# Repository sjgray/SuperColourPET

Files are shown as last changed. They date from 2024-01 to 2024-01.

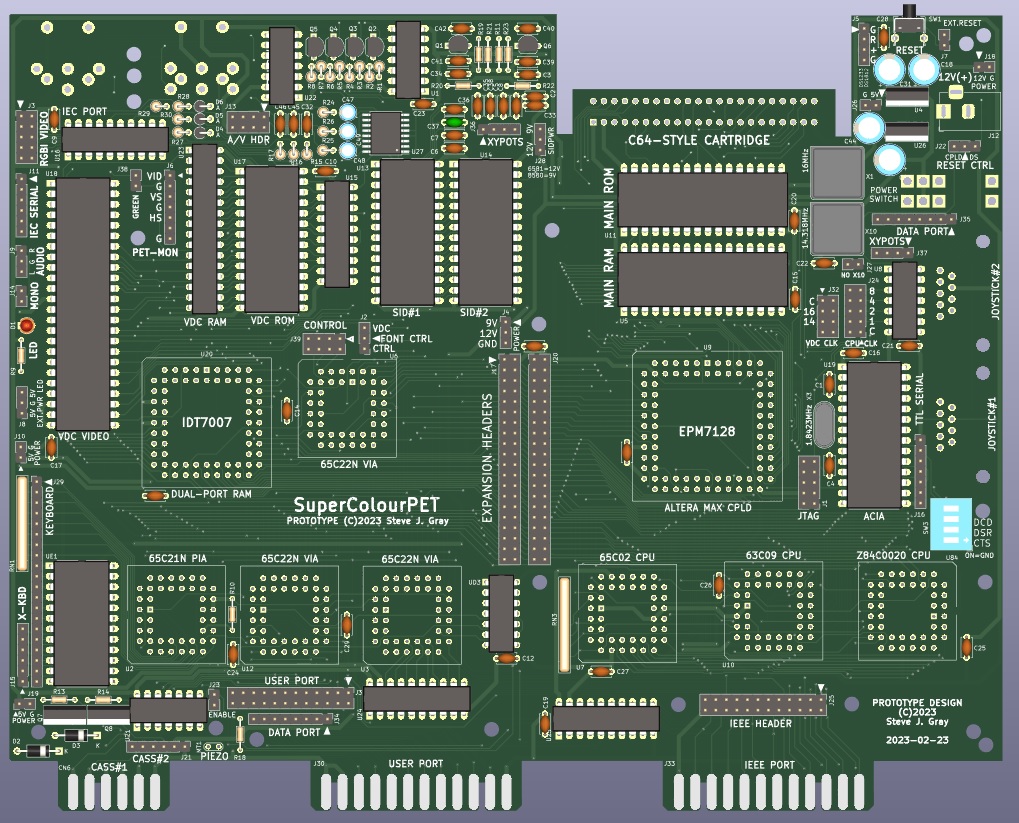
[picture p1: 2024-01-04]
PCB/Proto/_Pics/SuperColourPET-Render-2023-02-23.jpg

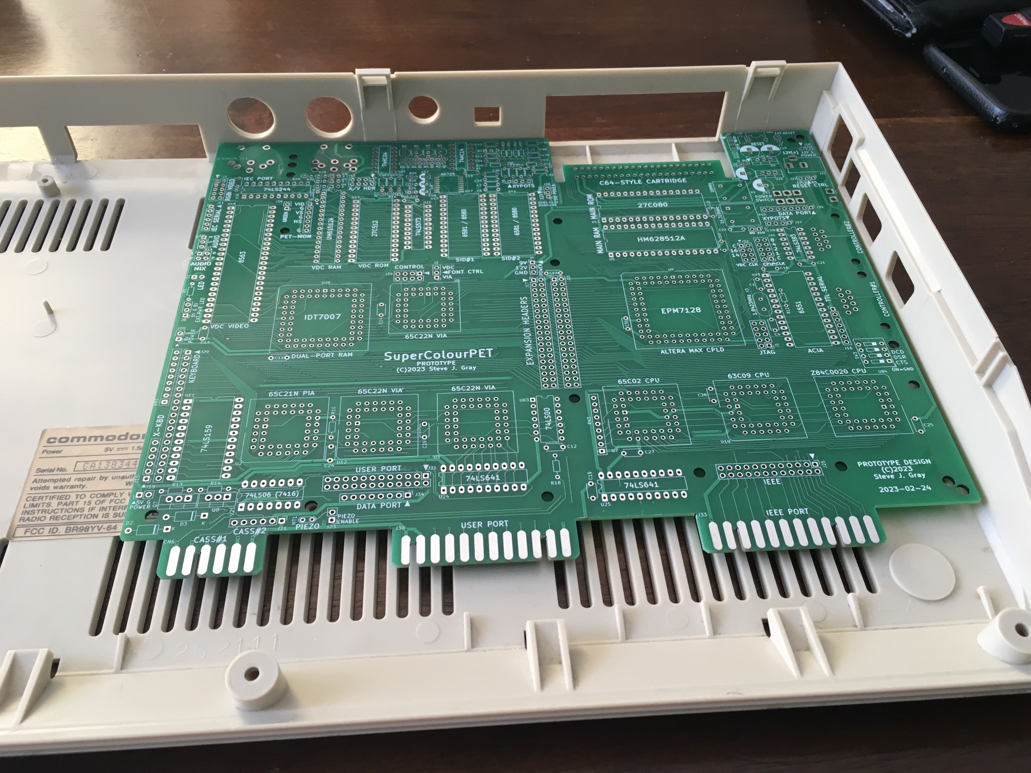
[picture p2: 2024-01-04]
PCB/Proto/_Pics/PCBs-Arrived-2023-03-02.jpg

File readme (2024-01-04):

SuperColourPET
==============

Introduction
------------

This is a project to create a Commodore SuperPET compatible computer with Colour. My ColourPET project aimed to add colour to a standard PET computer. While successful, ultimately I determined that adding all the features I wanted, like 80 column mode and graphics, would require too much hacking of a PET motherboard to be practical. So, I moved on to other projects. Recently I worked on the CLCD recreation project which provided the foundation for a nice 80 column 16-colour RGBI video using a 8563 VDC chip. This chip also supports graphics and software-defined fonts. I've also been interested in the dual-CPU SuperPET, with a 6809 CPU. So naturally I thought why not combine these things together? The result is the SuperColourPET (SCP). On top of that I wanted to go one more step to add a Z80 CPU for CP/M capabilities.

Recently there has been interest in PET replacement boards fitting in standard PET cases and talk of also putting them in C64 cases. Why not both? So I've come up with a single board design that will fit in PET, C64 (breadbin), and 64C cases. When installed in a PET case all three ports on the back will be the same as a regular PET board. The 2nd cassette port will be available on a header. When installed in a C64-type case it provides access to a C64 compatible audio/video port, semi-compatible C64 cartridge port, IEC port, power, and two configurable joystick ports. The board only takes up 2/3 of the C64 case and the C64 cassette and user-port cutouts will be free. I will be designing different boards that can be mounted here for access to PET cassette and USER port, or to IEEE and RGBI port etc. All the ports on the board have headers so you can select which ports you want to extend out those two openings.

Status
------

2023-02-24 - Prototype design complete. PCB's have been made. Project is on hold.
2024-01-04 - Github created. Posted Kicad design files.

*** The PROTO board has not been populated nor verified as working!!!!!
*** No CPLD code is written. Firmware is in planning stage.
*** This project should be considered as PRE-ALPHA! Use at own risk. Design subject to change!!!!!!!!!!!!!!!

That being said, much of the design is derived from my Commodore CLCD design, which is at the stage of basic
operation. The PET circuitry is based on the standard PET design. I am planning to build this bit-by-bit
starting with PET functionality and slowly adding the other CPU's over time. This is a long-term project!

Steve

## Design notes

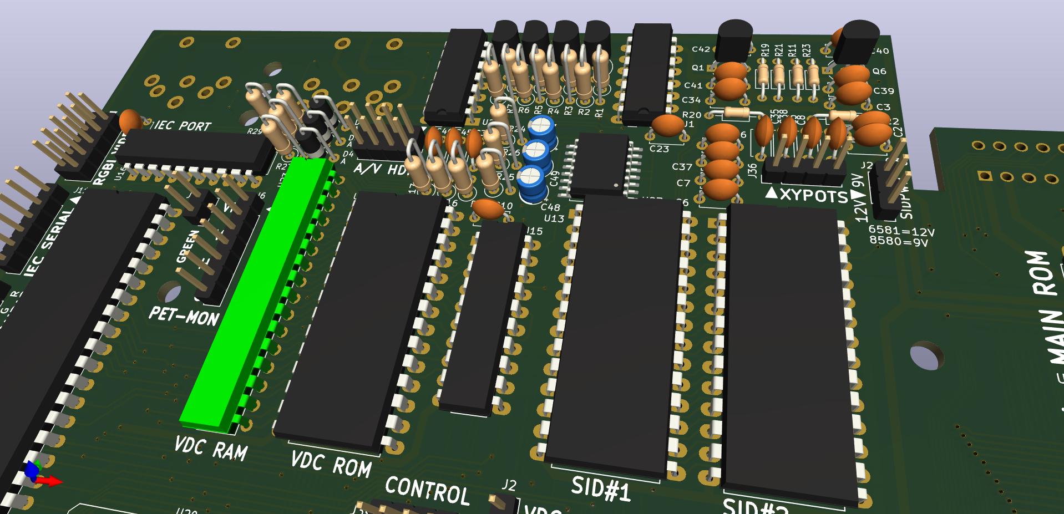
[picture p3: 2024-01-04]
PCB/Proto/_Pics/SuperColourPET-Render-2023-02-23b.jpg

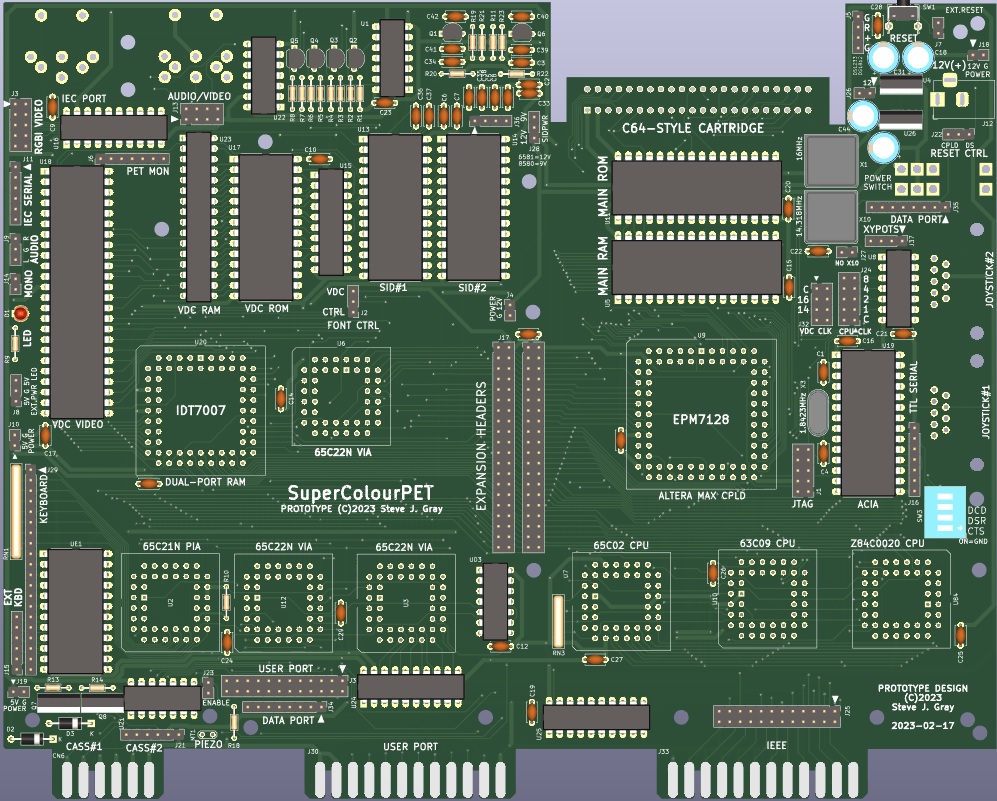
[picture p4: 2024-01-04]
PCB/Proto/_Pics/SuperColourPET.jpg

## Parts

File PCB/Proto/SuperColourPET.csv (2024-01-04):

Source: | C:\Users\sjgra\Desktop\Projects\KiCadProjects\SuperColourPET\SuperColourPET.kicad_sch
Date: | 2023-02-24 9:52:36 PM
Tool: | Eeschema (6.0.5)
Generator: | C:\Program Files\KiCad\6.0\bin\scripting\plugins/bom_csv_grouped_by_value.py
Component Count: | 178
Individual Components:
Item | Qty | Reference(s) | Value | LibPart | Footprint | Datasheet | Manufacturer_Name | Manufacturer_Part_Number
 |  | C1 | 10K | Super8296-rescue:C-superpet-rescue | Capacitor_THT:C_Disc_D4.7mm_W2.5mm_P5.00mm
 |  | C2 | .1 | Device:C_Small | Capacitor_THT:C_Disc_D4.7mm_W2.5mm_P5.00mm | ~
 |  | C3 | .1 | Device:C_Small | Capacitor_THT:C_Disc_D4.7mm_W2.5mm_P5.00mm | ~
 |  | C4 | 22pF | Super8296-rescue:C-superpet-rescue | Capacitor_THT:C_Disc_D4.7mm_W2.5mm_P5.00mm
 |  | C5 | 1800pF | Device:C_Small | Capacitor_THT:C_Disc_D4.7mm_W2.5mm_P5.00mm | ~
 |  | C6 | 470pF | Device:C_Small | Capacitor_THT:C_Disc_D4.7mm_W2.5mm_P5.00mm | ~
 |  | C7 | 470pF | Device:C_Small | Capacitor_THT:C_Disc_D4.7mm_W2.5mm_P5.00mm | ~
 |  | C8 | 1800pF | Device:C_Small | Capacitor_THT:C_Disc_D4.7mm_W2.5mm_P5.00mm | ~
 |  | C9 | 0.1 | device1:C_Small | Capacitor_THT:C_Disc_D4.7mm_W2.5mm_P5.00mm | ~
 |  | C10 | 0.1 | device1:C_Small | Capacitor_THT:C_Disc_D4.7mm_W2.5mm_P5.00mm | ~
 |  | C11 | 0.1 | device1:C_Small | Capacitor_THT:C_Disc_D4.7mm_W2.5mm_P5.00mm | ~
 |  | C12 | 0.1 | device1:C_Small | Capacitor_THT:C_Disc_D4.7mm_W2.5mm_P5.00mm | ~
 |  | C13 | 0.1 | device1:C_Small | Capacitor_THT:C_Disc_D4.7mm_W2.5mm_P5.00mm | ~
 |  | C14 | 0.1 | device1:C_Small | Capacitor_THT:C_Disc_D4.7mm_W2.5mm_P5.00mm | ~
 |  | C15 | 0.1 | device1:C_Small | Capacitor_THT:C_Disc_D4.7mm_W2.5mm_P5.00mm | ~
 |  | C16 | 0.1 | device1:C_Small | Capacitor_THT:C_Disc_D4.7mm_W2.5mm_P5.00mm | ~
 |  | C17 | 0.1 | device1:C_Small | Capacitor_THT:C_Disc_D4.7mm_W2.5mm_P5.00mm | ~
 |  | C18 | 10uF | Device:C_Polarized | Capacitor_THT:CP_Radial_D7.5mm_P2.50mm | ~
 |  | C19 | 0.1 | device1:C_Small | Capacitor_THT:C_Disc_D4.7mm_W2.5mm_P5.00mm | ~
 |  | C20 | 0.1 | device1:C_Small | Capacitor_THT:C_Disc_D4.7mm_W2.5mm_P5.00mm | ~
 |  | C21 | 0.1 | device1:C_Small | Capacitor_THT:C_Disc_D4.7mm_W2.5mm_P5.00mm | ~
 |  | C22 | 0.1 | device1:C_Small | Capacitor_THT:C_Disc_D4.7mm_W2.5mm_P5.00mm | ~
 |  | C23 | 0.1 | device1:C_Small | Capacitor_THT:C_Disc_D4.7mm_W2.5mm_P5.00mm | ~
 |  | C24 | 0.1 | device1:C_Small | Capacitor_THT:C_Disc_D4.7mm_W2.5mm_P5.00mm | ~
 |  | C25 | 0.1 | device1:C_Small | Capacitor_THT:C_Disc_D4.7mm_W2.5mm_P5.00mm | ~
 |  | C26 | 0.1 | device1:C_Small | Capacitor_THT:C_Disc_D4.7mm_W2.5mm_P5.00mm | ~
 |  | C27 | 0.1 | device1:C_Small | Capacitor_THT:C_Disc_D4.7mm_W2.5mm_P5.00mm | ~
 |  | C28 | 0.01uf * | device1:C_Small | Capacitor_THT:C_Disc_D4.7mm_W2.5mm_P5.00mm | ~
 |  | C29 | 0.1 | device1:C_Small | Capacitor_THT:C_Disc_D4.7mm_W2.5mm_P5.00mm | ~
 |  | C30 | 0.1 | device1:C_Small | Capacitor_THT:C_Disc_D4.7mm_W2.5mm_P5.00mm | ~
 |  | C31 | 10uF | Device:C_Polarized | Capacitor_THT:CP_Radial_D7.5mm_P2.50mm | ~
 |  | C32 | 0.1 | device1:C_Small | Capacitor_THT:C_Disc_D4.7mm_W2.5mm_P5.00mm | ~
 |  | C33 | .1 | Device:C_Small | Capacitor_THT:C_Disc_D4.7mm_W2.5mm_P5.00mm | ~
 |  | C34 | .1 | Device:C_Small | Capacitor_THT:C_Disc_D4.7mm_W2.5mm_P5.00mm | ~
 |  | C35 | 1800pF | Device:C_Small | Capacitor_THT:C_Disc_D4.7mm_W2.5mm_P5.00mm | ~
 |  | C36 | 470pF | Device:C_Small | Capacitor_THT:C_Disc_D4.7mm_W2.5mm_P5.00mm | ~
 |  | C37 | 470pF | Device:C_Small | Capacitor_THT:C_Disc_D4.7mm_W2.5mm_P5.00mm | ~
 |  | C38 | 1800pF | Device:C_Small | Capacitor_THT:C_Disc_D4.7mm_W2.5mm_P5.00mm | ~
 |  | C39 | NC | Device:C_Small | Capacitor_THT:C_Disc_D4.7mm_W2.5mm_P5.00mm | ~
 |  | C40 | .1 | Device:C_Small | Capacitor_THT:C_Disc_D4.7mm_W2.5mm_P5.00mm | ~
 |  | C41 | NC | Device:C_Small | Capacitor_THT:C_Disc_D4.7mm_W2.5mm_P5.00mm | ~
 |  | C42 | .1 | Device:C_Small | Capacitor_THT:C_Disc_D4.7mm_W2.5mm_P5.00mm | ~
 |  | C43 | 10uF | Device:C_Polarized | Capacitor_THT:CP_Radial_D7.5mm_P2.50mm | ~
 |  | C44 | 10uF | Device:C_Polarized | Capacitor_THT:CP_Radial_D7.5mm_P2.50mm | ~
 |  | C45 | 0.1 | device1:C_Small | Capacitor_THT:C_Disc_D4.7mm_W2.5mm_P5.00mm | ~
 |  | C46 | 0.1 | device1:C_Small | Capacitor_THT:C_Disc_D4.7mm_W2.5mm_P5.00mm | ~
 |  | C47 | 220uF | Device:C_Polarized | Capacitor_THT:CP_Radial_D4.0mm_P1.50mm | ~
 |  | C48 | 220uF | Device:C_Polarized | Capacitor_THT:CP_Radial_D4.0mm_P1.50mm | ~
 |  | C49 | 220uF | Device:C_Polarized | Capacitor_THT:CP_Radial_D4.0mm_P1.50mm | ~
 |  | C50 | 0.1 | device1:C_Small | Capacitor_THT:C_Disc_D4.7mm_W2.5mm_P5.00mm | ~
 |  | CN1 | SERIAL_BUS_CON | KU-schematics-library:SERIAL_BUS_CON | KU-14194HB-RevB-KiCad:SERIAL_CON_DIN6
 |  | CN2 | EXPANSION_PORT | KU-schematics-library:EXPANSION_PORT | KU-14194HB-RevB-KiCad:EXPANSION_PORT
 |  | CN6 | CASS1 | KU-schematics-library:CASSETTE_PORT_CON | KU-14194HB-RevB-KiCad:EDGE_CON_12P_TAPE
 |  | CN8 | CONTROL_PORT | KU-schematics-library:CONTROL_PORT | KU-14194HB-RevB-KiCad:JOYPORT_DB9
 |  | CN9 | CONTROL_PORT | KU-schematics-library:CONTROL_PORT | KU-14194HB-RevB-KiCad:JOYPORT_DB9
 |  | CN10 | AV_CONN | KU-schematics-library:AV_CONN | KU-14194HB-RevB-KiCad:AV_CON_DIN8
 |  | D1 | LED | Device:LED | LED_THT:LED_D3.0mm | ~
 |  | D2 | 7V5 | Device:D_Zener | Diode_THT:D_A-405_P10.16mm_Horizontal | ~
 |  | D3 | 7V5 | Device:D_Zener | Diode_THT:D_A-405_P10.16mm_Horizontal | ~
 |  | D4 | D | Device:D | Diode_THT:D_A-405_P2.54mm_Vertical_AnodeUp | ~
 |  | D5 | D | Device:D | Diode_THT:D_A-405_P2.54mm_Vertical_AnodeUp | ~
 |  | D6 | D | Device:D | Diode_THT:D_A-405_P2.54mm_Vertical_AnodeUp | ~
 |  | J1 | JTAG | Super8296-rescue:Conn_02x05_Odd_Even-superpet-rescue | Connector_PinHeader_2.54mm:PinHeader_2x05_P2.54mm_Vertical
 |  | J2 | GRAPHSEL | Connector_Generic:Conn_01x03 | Connector_PinHeader_2.54mm:PinHeader_1x03_P2.54mm_Vertical | ~
 |  | J3 | RGBI Header | Connector_Generic:Conn_02x05_Odd_Even | Connector_PinHeader_2.54mm:PinHeader_2x05_P2.54mm_Vertical | ~
 |  | J4 | POWER TAP | Connector_Generic:Conn_01x03 | Connector_PinHeader_2.54mm:PinHeader_1x03_P2.54mm_Vertical | ~
 |  | J5 | DS OPT | Connector_Generic:Conn_01x04 | Connector_PinHeader_2.54mm:PinHeader_1x04_P2.54mm_Vertical | ~
 |  | J6 | INTERNAL MONITOR | Connector_Generic:Conn_01x07 | Connector_PinHeader_2.54mm:PinHeader_1x07_P2.54mm_Vertical | ~
 |  | J7 | RESET | Connector_Generic:Conn_01x02 | Connector_PinHeader_2.54mm:PinHeader_1x02_P2.54mm_Vertical | ~
 |  | J8 | POWER LED | Connector_Generic:Conn_01x03 | Connector_PinHeader_2.54mm:PinHeader_1x03_P2.54mm_Vertical | ~
 |  | J9 | AUDIO | Connector_Generic:Conn_01x03 | Connector_PinHeader_2.54mm:PinHeader_1x03_P2.54mm_Vertical | ~
 |  | J10 | POWER5V | Connector_Generic:Conn_01x02 | Connector_PinHeader_2.54mm:PinHeader_1x02_P2.54mm_Vertical | ~
 |  | J11 | IEC Header | Connector_Generic:Conn_01x06 | Connector_PinHeader_2.54mm:PinHeader_1x06_P2.54mm_Vertical | ~
 |  | J12 | POWER_IN | Connector:Barrel_Jack_Switch | Connector_BarrelJack:BarrelJack_Horizontal | ~
 |  | J13 | AV HEADER | Connector_Generic:Conn_02x04_Odd_Even | Connector_PinHeader_2.54mm:PinHeader_2x04_P2.54mm_Vertical | ~
 |  | J14 | AUDIOMIX | Connector_Generic:Conn_02x02_Counter_Clockwise | Connector_PinHeader_2.54mm:PinHeader_2x02_P2.54mm_Vertical | ~
 |  | J15 | Extended Kbd | Connector_Generic:Conn_01x06 | Connector_PinHeader_2.54mm:PinHeader_1x06_P2.54mm_Vertical | ~
 |  | J16 | TTL Header | Connector_Generic:Conn_01x07 | Connector_PinHeader_2.54mm:PinHeader_1x07_P2.54mm_Vertical | ~
 |  | J17 | Expansion | Connector_Generic:Conn_02x20_Odd_Even | Connector_PinHeader_2.54mm:PinHeader_2x20_P2.54mm_Vertical | ~
 |  | J18 | POWER12V | Connector_Generic:Conn_01x02 | Connector_PinHeader_2.54mm:PinHeader_1x02_P2.54mm_Vertical | ~
 |  | J19 | POWER5V | Connector_Generic:Conn_01x02 | Connector_PinHeader_2.54mm:PinHeader_1x02_P2.54mm_Vertical | ~
 |  | J20 | Expansion | Connector_Generic:Conn_02x20_Odd_Even | Connector_PinHeader_2.54mm:PinHeader_2x20_P2.54mm_Vertical | ~
 |  | J21 | CASS2 | Connector_Generic:Conn_01x06 | Connector_PinHeader_2.54mm:PinHeader_1x06_P2.54mm_Vertical | ~
 |  | J22 | RESET | Connector_Generic:Conn_01x03 | Connector_PinHeader_2.54mm:PinHeader_1x03_P2.54mm_Vertical | ~
 |  | J23 | PIEZO ENABLE | Connector_Generic:Conn_01x02 | Connector_PinHeader_2.54mm:PinHeader_1x02_P2.54mm_Vertical | ~
 |  | J24 | CPU Clock | Connector_Generic:Conn_02x05_Odd_Even | Connector_PinHeader_2.54mm:PinHeader_2x05_P2.54mm_Vertical | ~
 |  | J25 | IEEE | Connector_Generic:Conn_02x12_Odd_Even | Connector_PinHeader_2.54mm:PinHeader_2x12_P2.54mm_Vertical | ~
 |  | J26 | POWER5V | Connector_Generic:Conn_01x02 | Connector_PinHeader_2.54mm:PinHeader_1x02_P2.54mm_Vertical | ~
 |  | J27 | NO-X10 | Connector_Generic:Conn_01x02 | Connector_PinHeader_2.54mm:PinHeader_1x02_P2.54mm_Vertical | ~
 |  | J28 | SIDPWR | Connector_Generic:Conn_01x03 | Connector_PinHeader_2.54mm:PinHeader_1x03_P2.54mm_Vertical | ~
 |  | J29 | PET KEYBOARD | Connector_Generic:Conn_01x20 | Connector_PinHeader_2.54mm:PinHeader_1x20_P2.54mm_Vertical | ~
 |  | J30 | USERPORT | Super8296-rescue:EDGE_CON_02x12-cbm | KU-14194HB-RevB-KiCad:EDGE_CON_24P
 |  | J31 | USERPORT | Connector_Generic:Conn_02x12_Odd_Even | Connector_PinHeader_2.54mm:PinHeader_2x12_P2.54mm_Vertical | ~
 |  | J32 | VDC Clock | Connector_Generic:Conn_02x04_Odd_Even | Connector_PinHeader_2.54mm:PinHeader_2x04_P2.54mm_Vertical | ~
 |  | J33 | IEEE | Super8296-rescue:EDGE_CON_02x12-cbm | KU-14194HB-RevB-KiCad:EDGE_CON_24P
 |  | J34 | USERDATA | Connector_Generic:Conn_01x08 | Connector_PinHeader_2.54mm:PinHeader_1x08_P2.54mm_Vertical | ~
 |  | J35 | USERJOY | Connector_Generic:Conn_01x08 | Connector_PinHeader_2.54mm:PinHeader_1x08_P2.54mm_Vertical | ~
 |  | J36 | POTS | Connector_Generic:Conn_01x04 | Connector_PinHeader_2.54mm:PinHeader_1x04_P2.54mm_Vertical | ~
 |  | J37 | POTS | Connector_Generic:Conn_01x04 | Connector_PinHeader_2.54mm:PinHeader_1x04_P2.54mm_Vertical | ~
 |  | J38 | VID-GRN | Connector_Generic:Conn_01x02 | Connector_PinHeader_2.54mm:PinHeader_1x02_P2.54mm_Vertical | ~
 |  | J39 | Control | Connector_Generic:Conn_02x04_Odd_Even | Connector_PinHeader_2.54mm:PinHeader_2x04_P2.54mm_Vertical | ~
 |  | MT1 | Piezo | Device:Speaker | TestPoint:TestPoint_2Pads_Pitch2.54mm_Drill0.8mm | ~
 |  | Q1 | 2SC1815 | Transistor_BJT:2SC1815 | Package_TO_SOT_THT:TO-92_Inline_Wide | https://media.digikey.com/pdf/Data%20Sheets/Toshiba%20PDFs/2SC1815.pdf
 |  | Q2 | 2N3904 | Transistor_BJT:2N3904 | Package_TO_SOT_THT:TO-92_Inline_Wide | https://www.onsemi.com/pub/Collateral/2N3903-D.PDF
 |  | Q3 | 2N3904 | Transistor_BJT:2N3904 | Package_TO_SOT_THT:TO-92_Inline_Wide | https://www.onsemi.com/pub/Collateral/2N3903-D.PDF
 |  | Q4 | 2N3904 | Transistor_BJT:2N3904 | Package_TO_SOT_THT:TO-92_Inline_Wide | https://www.onsemi.com/pub/Collateral/2N3903-D.PDF
 |  | Q5 | 2N3904 | Transistor_BJT:2N3904 | Package_TO_SOT_THT:TO-92_Inline_Wide | https://www.onsemi.com/pub/Collateral/2N3903-D.PDF
 |  | Q6 | 2SC1815 | Transistor_BJT:2SC1815 | Package_TO_SOT_THT:TO-92_Inline_Wide | https://media.digikey.com/pdf/Data%20Sheets/Toshiba%20PDFs/2SC1815.pdf
 |  | Q7 | TIP110 | Device:Q_NPN_Darlington_BCE | Package_TO_SOT_THT:TO-220-3_Vertical | ~
 |  | Q8 | TIP110 | Device:Q_NPN_Darlington_BCE | Package_TO_SOT_THT:TO-220-3_Vertical | ~
 |  | R1 | 1K | Device:R | Resistor_THT:R_Axial_DIN0207_L6.3mm_D2.5mm_P2.54mm_Vertical | ~
 |  | R2 | 4K7 | Device:R | Resistor_THT:R_Axial_DIN0207_L6.3mm_D2.5mm_P2.54mm_Vertical | ~
 |  | R3 | 4K7 | Device:R | Resistor_THT:R_Axial_DIN0207_L6.3mm_D2.5mm_P2.54mm_Vertical | ~
 |  | R4 | 4K7 | Device:R | Resistor_THT:R_Axial_DIN0207_L6.3mm_D2.5mm_P2.54mm_Vertical | ~
 |  | R5 | 1K | Device:R | Resistor_THT:R_Axial_DIN0207_L6.3mm_D2.5mm_P2.54mm_Vertical | ~
 |  | R6 | 4K7 | Device:R | Resistor_THT:R_Axial_DIN0207_L6.3mm_D2.5mm_P2.54mm_Vertical | ~
 |  | R7 | 1K | Device:R | Resistor_THT:R_Axial_DIN0207_L6.3mm_D2.5mm_P2.54mm_Vertical | ~
 |  | R8 | 4K7 | Device:R | Resistor_THT:R_Axial_DIN0207_L6.3mm_D2.5mm_P2.54mm_Vertical | ~
 |  | R9 | 10K | KU-schematics-library:R_US_CUSTOM | Resistor_THT:R_Axial_DIN0204_L3.6mm_D1.6mm_P7.62mm_Horizontal
 |  | R10 | 1K | Device:R | Resistor_THT:R_Axial_DIN0204_L3.6mm_D1.6mm_P7.62mm_Horizontal | ~
 |  | R11 | 1K | KU-schematics-library:R_US_CUSTOM | Resistor_THT:R_Axial_DIN0204_L3.6mm_D1.6mm_P7.62mm_Horizontal
 |  | R12 | 1M | Device:R | Resistor_THT:R_Axial_DIN0204_L3.6mm_D1.6mm_P7.62mm_Horizontal | ~
 |  | R13 | R | Device:R | Resistor_THT:R_Axial_DIN0204_L3.6mm_D1.6mm_P7.62mm_Horizontal | ~
 |  | R14 | R | Device:R | Resistor_THT:R_Axial_DIN0204_L3.6mm_D1.6mm_P7.62mm_Horizontal | ~
 |  | R15 | 75R | Device:R | Resistor_THT:R_Axial_DIN0207_L6.3mm_D2.5mm_P2.54mm_Vertical | ~
 |  | R16 | 75R | Device:R | Resistor_THT:R_Axial_DIN0207_L6.3mm_D2.5mm_P2.54mm_Vertical | ~
 |  | R17 | 75R | Device:R | Resistor_THT:R_Axial_DIN0207_L6.3mm_D2.5mm_P2.54mm_Vertical | ~
 |  | R18 | 10 ohm | device1:R | Resistor_THT:R_Axial_DIN0204_L3.6mm_D1.6mm_P7.62mm_Horizontal | ~
 |  | R19 | 1K | KU-schematics-library:R_US_CUSTOM | Resistor_THT:R_Axial_DIN0204_L3.6mm_D1.6mm_P7.62mm_Horizontal
 |  | R20 | 10K | KU-schematics-library:R_US_CUSTOM | Resistor_THT:R_Axial_DIN0204_L3.6mm_D1.6mm_P7.62mm_Horizontal
 |  | R21 | 1K | KU-schematics-library:R_US_CUSTOM | Resistor_THT:R_Axial_DIN0204_L3.6mm_D1.6mm_P7.62mm_Horizontal
 |  | R22 | 10K | KU-schematics-library:R_US_CUSTOM | Resistor_THT:R_Axial_DIN0204_L3.6mm_D1.6mm_P7.62mm_Horizontal
 |  | R23 | 1K | KU-schematics-library:R_US_CUSTOM | Resistor_THT:R_Axial_DIN0204_L3.6mm_D1.6mm_P7.62mm_Horizontal
 |  | R24 | 75R | Device:R | Resistor_THT:R_Axial_DIN0207_L6.3mm_D2.5mm_P2.54mm_Vertical | ~
 |  | R25 | 75R | Device:R | Resistor_THT:R_Axial_DIN0207_L6.3mm_D2.5mm_P2.54mm_Vertical | ~
 |  | R26 | 75R | Device:R | Resistor_THT:R_Axial_DIN0207_L6.3mm_D2.5mm_P2.54mm_Vertical | ~
 |  | R27 | 75R | Device:R | Resistor_THT:R_Axial_DIN0207_L6.3mm_D2.5mm_P2.54mm_Vertical | ~
 |  | R28 | 75R | Device:R | Resistor_THT:R_Axial_DIN0207_L6.3mm_D2.5mm_P2.54mm_Vertical | ~
 |  | R29 | 75R | Device:R | Resistor_THT:R_Axial_DIN0207_L6.3mm_D2.5mm_P2.54mm_Vertical | ~
 |  | R30 | 75R | Device:R | Resistor_THT:R_Axial_DIN0207_L6.3mm_D2.5mm_P2.54mm_Vertical | ~
 |  | RN1 | 10K | Device:R_Network08_US | Resistor_THT:R_Array_SIP9 | http://www.vishay.com/docs/31509/csc.pdf
 |  | RN3 | CPU pullups | Device:R_Network08 | Resistor_THT:R_Array_SIP9 | http://www.vishay.com/docs/31509/csc.pdf
 |  | SW1 | RESET | Switch:SW_Push | Button_Switch_THT:SW_Tactile_SPST_Angled_PTS645Vx58-2LFS | ~
 |  | SW3 | COM Lines | Switch:SW_DIP_x04 | Button_Switch_THT:SW_DIP_SPSTx04_Slide_9.78x12.34mm_W7.62mm_P2.54mm | ~
 |  | SW4 | POWER_SWITCH | KU-schematics-library:POWER_SWITCH | KU-14194HB-RevB-KiCad:POWER_SWITCH
 |  | U1 | 74HC14 | 74xx:74HC14 | Package_DIP:DIP-14_W7.62mm_LongPads | http://www.ti.com/lit/gpn/sn74HC14
 |  | U2 | W65C21NxPL | 65xx:W65C21NxPL | Package_LCC:PLCC-44_THT-Socket | http://www.westerndesigncenter.com/wdc/documentation/w65c21.pdf
 |  | U3 | W65C21NxPL | 65xx:W65C21NxPL | Package_LCC:PLCC-44_THT-Socket | http://www.westerndesigncenter.com/wdc/documentation/w65c21.pdf
 |  | U4 | LM7805_TO220 | Regulator_Linear:LM7805_TO220 | Package_TO_SOT_THT:TO-220-3_Vertical | https://www.onsemi.cn/PowerSolutions/document/MC7800-D.PDF
 |  | U5 | HM628512A | Super8296-rescue:HM628512A-superpet-rescue | Package_DIP:DIP-32_W15.24mm_LongPads
 |  | U6 | W65C22NxPL | 65xx:W65C22NxPL | Package_LCC:PLCC-44_THT-Socket | http://www.westerndesigncenter.com/wdc/documentation/w65c22.pdf
 |  | U7 | W65C02SxPL | 65xx:W65C02SxPL | Package_LCC:PLCC-44_THT-Socket | http://www.westerndesigncenter.com/wdc/documentation/w65c02s.pdf
 |  | U8 | 74LS393 | 74xx:74LS393 | Package_DIP:DIP-14_W7.62mm_LongPads | 74xx\74LS393.pdf
 |  | U9 | EPM7128S | Super8296-rescue:EPM7128S-superpet-rescue | Package_LCC:PLCC-84_THT-Socket
 |  | U10 | MC6809E-PLCC | cbm-steve:MC6809E-PLCC | Package_LCC:PLCC-44_THT-Socket
 |  | U11 | 27C080 | Memory_EPROM:27C080 | Package_DIP:DIP-32_W15.24mm_LongPads | http://ww1.microchip.com/downloads/en/devicedoc/doc0360.pdf
 |  | U12 | W65C22NxPL | 65xx:W65C22NxPL | Package_LCC:PLCC-44_THT-Socket | http://www.westerndesigncenter.com/wdc/documentation/w65c22.pdf
 |  | U13 | 6581 | KU-schematics-library:SID | Package_DIP:DIP-28_W15.24mm_LongPads
 |  | U14 | 6581 | KU-schematics-library:SID | Package_DIP:DIP-28_W15.24mm_LongPads
 |  | U15 | 74LS573 | 74xx:74LS573 | Package_DIP:DIP-20_W7.62mm_LongPads | 74xx/74hc573.pdf
 |  | U16 | 74LS244 | 74xx:74LS244 | Package_DIP:DIP-20_W7.62mm_LongPads | http://www.ti.com/lit/ds/symlink/sn74ls244.pdf
 |  | U17 | 27C512 | cbm:27C512 | Package_DIP:DIP-28_W15.24mm_LongPads
 |  | U18 | 8563 | cbm:8563 | Package_DIP:DIP-48_W15.24mm_LongPads
 |  | U19 | 6551 | Super8296-rescue:6551-superpet-rescue | Package_DIP:DIP-28_W15.24mm_LongPads
 |  | U20 | IDT7007PLCC | cbm:IDT7007PLCC | Package_LCC:PLCC-68_THT-Socket
 |  | U21 | 7416 | 74xx_IEEE:7416 | Package_DIP:DIP-14_W7.62mm_LongPads
 |  | U22 | 74LS04 | 74xx:74LS04 | Package_DIP:DIP-14_W7.62mm_LongPads | http://www.ti.com/lit/gpn/sn74LS04
 |  | U23 | UM61512A | cbm-steve:UM61512A | Package_DIP:DIP-32_W7.62mm
 |  | U24 | 74LS641 | 74xx_IEEE:74LS641 | Package_DIP:DIP-20_W7.62mm_LongPads
 |  | U25 | 74LS641 | 74xx_IEEE:74LS641 | Package_DIP:DIP-20_W7.62mm_LongPads
 |  | U26 | LM7809_TO220 | Regulator_Linear:LM7809_TO220 | Package_TO_SOT_THT:TO-220-3_Vertical | https://www.onsemi.cn/PowerSolutions/document/MC7800-D.PDF
 |  | U27 | AD725 | Video:AD725 | Package_SO:SOIC-16W_7.5x10.3mm_P1.27mm | https://www.analog.com/media/en/technical-documentation/data-sheets/AD725.pdf
 |  | U84 | Z80CPU-LCC | Zilog_z80:Z80CPU-LCC | Package_LCC:PLCC-44_THT-Socket | https://www.mouser.co.uk/datasheet/2/450/ps0178-19386.pdf | Zilog | Z84C00
 |  | UD3 | 74LS00 | 74xx:74LS00 | Package_DIP:DIP-14_W7.62mm | http://www.ti.com/lit/gpn/sn74ls00
 |  | UE1 | 74159 | 74xx_IEEE:74159 | Package_DIP:DIP-24_W15.24mm_LongPads
 |  | X1 | CXO_DIP8 | Oscillator:CXO_DIP8 | Oscillator:Oscillator_DIP-8 | http://cdn-reichelt.de/documents/datenblatt/B400/OSZI.pdf
 |  | X3 | 1.8432 MHz, HC49U | Super8296-rescue:Crystal-superpet-rescue | Crystal:Crystal_HC49-U_Vertical
 |  | X10 | CXO_DIP8 | Oscillator:CXO_DIP8 | Oscillator:Oscillator_DIP-8 | http://cdn-reichelt.de/documents/datenblatt/B400/OSZI.pdf
Collated Components:
Item | Qty | Reference(s) | Value | LibPart | Footprint | Datasheet | Manufacturer_Name | Manufacturer_Part_Number
1 | 1 | C1 | 10K | Super8296-rescue:C-superpet-rescue | Capacitor_THT:C_Disc_D4.7mm_W2.5mm_P5.00mm
2 | 6 | C2, C3, C33, C34, C40, C42 | .1 | Device:C_Small | Capacitor_THT:C_Disc_D4.7mm_W2.5mm_P5.00mm | ~
3 | 1 | C4 | 22pF | Super8296-rescue:C-superpet-rescue | Capacitor_THT:C_Disc_D4.7mm_W2.5mm_P5.00mm
4 | 4 | C5, C8, C35, C38 | 1800pF | Device:C_Small | Capacitor_THT:C_Disc_D4.7mm_W2.5mm_P5.00mm | ~
5 | 4 | C6, C7, C36, C37 | 470pF | Device:C_Small | Capacitor_THT:C_Disc_D4.7mm_W2.5mm_P5.00mm | ~
6 | 24 | C9, C10, C11, C12, C13, C14, C15, C16, C17, C19, C20, C21, C22, C23, C24, C25, C26, C27, C29, C30, C32, C45, C46, C50 | 0.1 | device1:C_Small | Capacitor_THT:C_Disc_D4.7mm_W2.5mm_P5.00mm | ~
7 | 4 | C18, C31, C43, C44 | 10uF | Device:C_Polarized | Capacitor_THT:CP_Radial_D7.5mm_P2.50mm | ~
8 | 1 | C28 | 0.01uf * | device1:C_Small | Capacitor_THT:C_Disc_D4.7mm_W2.5mm_P5.00mm | ~
9 | 2 | C39, C41 | NC | Device:C_Small | Capacitor_THT:C_Disc_D4.7mm_W2.5mm_P5.00mm | ~
10 | 3 | C47, C48, C49 | 220uF | Device:C_Polarized | Capacitor_THT:CP_Radial_D4.0mm_P1.50mm | ~
11 | 1 | CN1 | SERIAL_BUS_CON | KU-schematics-library:SERIAL_BUS_CON | KU-14194HB-RevB-KiCad:SERIAL_CON_DIN6
12 | 1 | CN2 | EXPANSION_PORT | KU-schematics-library:EXPANSION_PORT | KU-14194HB-RevB-KiCad:EXPANSION_PORT
13 | 1 | CN6 | CASS1 | KU-schematics-library:CASSETTE_PORT_CON | KU-14194HB-RevB-KiCad:EDGE_CON_12P_TAPE
14 | 2 | CN8, CN9 | CONTROL_PORT | KU-schematics-library:CONTROL_PORT | KU-14194HB-RevB-KiCad:JOYPORT_DB9
15 | 1 | CN10 | AV_CONN | KU-schematics-library:AV_CONN | KU-14194HB-RevB-KiCad:AV_CON_DIN8
16 | 1 | D1 | LED | Device:LED | LED_THT:LED_D3.0mm | ~
17 | 2 | D2, D3 | 7V5 | Device:D_Zener | Diode_THT:D_A-405_P10.16mm_Horizontal | ~
18 | 3 | D4, D5, D6 | D | Device:D | Diode_THT:D_A-405_P2.54mm_Vertical_AnodeUp | ~
19 | 1 | J1 | JTAG | Super8296-rescue:Conn_02x05_Odd_Even-superpet-rescue | Connector_PinHeader_2.54mm:PinHeader_2x05_P2.54mm_Vertical
20 | 1 | J2 | GRAPHSEL | Connector_Generic:Conn_01x03 | Connector_PinHeader_2.54mm:PinHeader_1x03_P2.54mm_Vertical | ~
21 | 1 | J3 | RGBI Header | Connector_Generic:Conn_02x05_Odd_Even | Connector_PinHeader_2.54mm:PinHeader_2x05_P2.54mm_Vertical | ~
22 | 1 | J4 | POWER TAP | Connector_Generic:Conn_01x03 | Connector_PinHeader_2.54mm:PinHeader_1x03_P2.54mm_Vertical | ~
23 | 1 | J5 | DS OPT | Connector_Generic:Conn_01x04 | Connector_PinHeader_2.54mm:PinHeader_1x04_P2.54mm_Vertical | ~
24 | 1 | J6 | INTERNAL MONITOR | Connector_Generic:Conn_01x07 | Connector_PinHeader_2.54mm:PinHeader_1x07_P2.54mm_Vertical | ~
25 | 1 | J7 | RESET | Connector_Generic:Conn_01x02 | Connector_PinHeader_2.54mm:PinHeader_1x02_P2.54mm_Vertical | ~
26 | 1 | J8 | POWER LED | Connector_Generic:Conn_01x03 | Connector_PinHeader_2.54mm:PinHeader_1x03_P2.54mm_Vertical | ~
27 | 1 | J9 | AUDIO | Connector_Generic:Conn_01x03 | Connector_PinHeader_2.54mm:PinHeader_1x03_P2.54mm_Vertical | ~
28 | 3 | J10, J19, J26 | POWER5V | Connector_Generic:Conn_01x02 | Connector_PinHeader_2.54mm:PinHeader_1x02_P2.54mm_Vertical | ~
29 | 1 | J11 | IEC Header | Connector_Generic:Conn_01x06 | Connector_PinHeader_2.54mm:PinHeader_1x06_P2.54mm_Vertical | ~
30 | 1 | J12 | POWER_IN | Connector:Barrel_Jack_Switch | Connector_BarrelJack:BarrelJack_Horizontal | ~
31 | 1 | J13 | AV HEADER | Connector_Generic:Conn_02x04_Odd_Even | Connector_PinHeader_2.54mm:PinHeader_2x04_P2.54mm_Vertical | ~
32 | 1 | J14 | AUDIOMIX | Connector_Generic:Conn_02x02_Counter_Clockwise | Connector_PinHeader_2.54mm:PinHeader_2x02_P2.54mm_Vertical | ~
33 | 1 | J15 | Extended Kbd | Connector_Generic:Conn_01x06 | Connector_PinHeader_2.54mm:PinHeader_1x06_P2.54mm_Vertical | ~
34 | 1 | J16 | TTL Header | Connector_Generic:Conn_01x07 | Connector_PinHeader_2.54mm:PinHeader_1x07_P2.54mm_Vertical | ~
35 | 2 | J17, J20 | Expansion | Connector_Generic:Conn_02x20_Odd_Even | Connector_PinHeader_2.54mm:PinHeader_2x20_P2.54mm_Vertical | ~
36 | 1 | J18 | POWER12V | Connector_Generic:Conn_01x02 | Connector_PinHeader_2.54mm:PinHeader_1x02_P2.54mm_Vertical | ~
37 | 1 | J21 | CASS2 | Connector_Generic:Conn_01x06 | Connector_PinHeader_2.54mm:PinHeader_1x06_P2.54mm_Vertical | ~
38 | 1 | J22 | RESET | Connector_Generic:Conn_01x03 | Connector_PinHeader_2.54mm:PinHeader_1x03_P2.54mm_Vertical | ~
39 | 1 | J23 | PIEZO ENABLE | Connector_Generic:Conn_01x02 | Connector_PinHeader_2.54mm:PinHeader_1x02_P2.54mm_Vertical | ~
40 | 1 | J24 | CPU Clock | Connector_Generic:Conn_02x05_Odd_Even | Connector_PinHeader_2.54mm:PinHeader_2x05_P2.54mm_Vertical | ~
41 | 1 | J25 | IEEE | Connector_Generic:Conn_02x12_Odd_Even | Connector_PinHeader_2.54mm:PinHeader_2x12_P2.54mm_Vertical | ~
42 | 1 | J27 | NO-X10 | Connector_Generic:Conn_01x02 | Connector_PinHeader_2.54mm:PinHeader_1x02_P2.54mm_Vertical | ~
43 | 1 | J28 | SIDPWR | Connector_Generic:Conn_01x03 | Connector_PinHeader_2.54mm:PinHeader_1x03_P2.54mm_Vertical | ~
44 | 1 | J29 | PET KEYBOARD | Connector_Generic:Conn_01x20 | Connector_PinHeader_2.54mm:PinHeader_1x20_P2.54mm_Vertical | ~
45 | 1 | J30 | USERPORT | Super8296-rescue:EDGE_CON_02x12-cbm | KU-14194HB-RevB-KiCad:EDGE_CON_24P
46 | 1 | J31 | USERPORT | Connector_Generic:Conn_02x12_Odd_Even | Connector_PinHeader_2.54mm:PinHeader_2x12_P2.54mm_Vertical | ~
47 | 1 | J32 | VDC Clock | Connector_Generic:Conn_02x04_Odd_Even | Connector_PinHeader_2.54mm:PinHeader_2x04_P2.54mm_Vertical | ~
48 | 1 | J33 | IEEE | Super8296-rescue:EDGE_CON_02x12-cbm | KU-14194HB-RevB-KiCad:EDGE_CON_24P
49 | 1 | J34 | USERDATA | Connector_Generic:Conn_01x08 | Connector_PinHeader_2.54mm:PinHeader_1x08_P2.54mm_Vertical | ~
50 | 1 | J35 | USERJOY | Connector_Generic:Conn_01x08 | Connector_PinHeader_2.54mm:PinHeader_1x08_P2.54mm_Vertical | ~
51 | 2 | J36, J37 | POTS | Connector_Generic:Conn_01x04 | Connector_PinHeader_2.54mm:PinHeader_1x04_P2.54mm_Vertical | ~
52 | 1 | J38 | VID-GRN | Connector_Generic:Conn_01x02 | Connector_PinHeader_2.54mm:PinHeader_1x02_P2.54mm_Vertical | ~
53 | 1 | J39 | Control | Connector_Generic:Conn_02x04_Odd_Even | Connector_PinHeader_2.54mm:PinHeader_2x04_P2.54mm_Vertical | ~
54 | 1 | MT1 | Piezo | Device:Speaker | TestPoint:TestPoint_2Pads_Pitch2.54mm_Drill0.8mm | ~
55 | 2 | Q1, Q6 | 2SC1815 | Transistor_BJT:2SC1815 | Package_TO_SOT_THT:TO-92_Inline_Wide | https://media.digikey.com/pdf/Data%20Sheets/Toshiba%20PDFs/2SC1815.pdf
56 | 4 | Q2, Q3, Q4, Q5 | 2N3904 | Transistor_BJT:2N3904 | Package_TO_SOT_THT:TO-92_Inline_Wide | https://www.onsemi.com/pub/Collateral/2N3903-D.PDF
57 | 2 | Q7, Q8 | TIP110 | Device:Q_NPN_Darlington_BCE | Package_TO_SOT_THT:TO-220-3_Vertical | ~
58 | 3 | R1, R5, R7 | 1K | Device:R | Resistor_THT:R_Axial_DIN0207_L6.3mm_D2.5mm_P2.54mm_Vertical | ~
59 | 5 | R2, R3, R4, R6, R8 | 4K7 | Device:R | Resistor_THT:R_Axial_DIN0207_L6.3mm_D2.5mm_P2.54mm_Vertical | ~
60 | 3 | R9, R20, R22 | 10K | KU-schematics-library:R_US_CUSTOM | Resistor_THT:R_Axial_DIN0204_L3.6mm_D1.6mm_P7.62mm_Horizontal
61 | 1 | R10 | 1K | Device:R | Resistor_THT:R_Axial_DIN0204_L3.6mm_D1.6mm_P7.62mm_Horizontal | ~
62 | 4 | R11, R19, R21, R23 | 1K | KU-schematics-library:R_US_CUSTOM | Resistor_THT:R_Axial_DIN0204_L3.6mm_D1.6mm_P7.62mm_Horizontal
63 | 1 | R12 | 1M | Device:R | Resistor_THT:R_Axial_DIN0204_L3.6mm_D1.6mm_P7.62mm_Horizontal | ~
64 | 2 | R13, R14 | R | Device:R | Resistor_THT:R_Axial_DIN0204_L3.6mm_D1.6mm_P7.62mm_Horizontal | ~
65 | 10 | R15, R16, R17, R24, R25, R26, R27, R28, R29, R30 | 75R | Device:R | Resistor_THT:R_Axial_DIN0207_L6.3mm_D2.5mm_P2.54mm_Vertical | ~
66 | 1 | R18 | 10 ohm | device1:R | Resistor_THT:R_Axial_DIN0204_L3.6mm_D1.6mm_P7.62mm_Horizontal | ~
67 | 1 | RN1 | 10K | Device:R_Network08_US | Resistor_THT:R_Array_SIP9 | http://www.vishay.com/docs/31509/csc.pdf
68 | 1 | RN3 | CPU pullups | Device:R_Network08 | Resistor_THT:R_Array_SIP9 | http://www.vishay.com/docs/31509/csc.pdf
69 | 1 | SW1 | RESET | Switch:SW_Push | Button_Switch_THT:SW_Tactile_SPST_Angled_PTS645Vx58-2LFS | ~
70 | 1 | SW3 | COM Lines | Switch:SW_DIP_x04 | Button_Switch_THT:SW_DIP_SPSTx04_Slide_9.78x12.34mm_W7.62mm_P2.54mm | ~
71 | 1 | SW4 | POWER_SWITCH | KU-schematics-library:POWER_SWITCH | KU-14194HB-RevB-KiCad:POWER_SWITCH
72 | 1 | U1 | 74HC14 | 74xx:74HC14 | Package_DIP:DIP-14_W7.62mm_LongPads | http://www.ti.com/lit/gpn/sn74HC14
73 | 2 | U2, U3 | W65C21NxPL | 65xx:W65C21NxPL | Package_LCC:PLCC-44_THT-Socket | http://www.westerndesigncenter.com/wdc/documentation/w65c21.pdf
74 | 1 | U4 | LM7805_TO220 | Regulator_Linear:LM7805_TO220 | Package_TO_SOT_THT:TO-220-3_Vertical | https://www.onsemi.cn/PowerSolutions/document/MC7800-D.PDF
75 | 1 | U5 | HM628512A | Super8296-rescue:HM628512A-superpet-rescue | Package_DIP:DIP-32_W15.24mm_LongPads
76 | 2 | U6, U12 | W65C22NxPL | 65xx:W65C22NxPL | Package_LCC:PLCC-44_THT-Socket | http://www.westerndesigncenter.com/wdc/documentation/w65c22.pdf
77 | 1 | U7 | W65C02SxPL | 65xx:W65C02SxPL | Package_LCC:PLCC-44_THT-Socket | http://www.westerndesigncenter.com/wdc/documentation/w65c02s.pdf
78 | 1 | U8 | 74LS393 | 74xx:74LS393 | Package_DIP:DIP-14_W7.62mm_LongPads | 74xx\74LS393.pdf
79 | 1 | U9 | EPM7128S | Super8296-rescue:EPM7128S-superpet-rescue | Package_LCC:PLCC-84_THT-Socket
80 | 1 | U10 | MC6809E-PLCC | cbm-steve:MC6809E-PLCC | Package_LCC:PLCC-44_THT-Socket
81 | 1 | U11 | 27C080 | Memory_EPROM:27C080 | Package_DIP:DIP-32_W15.24mm_LongPads | http://ww1.microchip.com/downloads/en/devicedoc/doc0360.pdf
82 | 2 | U13, U14 | 6581 | KU-schematics-library:SID | Package_DIP:DIP-28_W15.24mm_LongPads
83 | 1 | U15 | 74LS573 | 74xx:74LS573 | Package_DIP:DIP-20_W7.62mm_LongPads | 74xx/74hc573.pdf
84 | 1 | U16 | 74LS244 | 74xx:74LS244 | Package_DIP:DIP-20_W7.62mm_LongPads | http://www.ti.com/lit/ds/symlink/sn74ls244.pdf
85 | 1 | U17 | 27C512 | cbm:27C512 | Package_DIP:DIP-28_W15.24mm_LongPads
86 | 1 | U18 | 8563 | cbm:8563 | Package_DIP:DIP-48_W15.24mm_LongPads
87 | 1 | U19 | 6551 | Super8296-rescue:6551-superpet-rescue | Package_DIP:DIP-28_W15.24mm_LongPads
88 | 1 | U20 | IDT7007PLCC | cbm:IDT7007PLCC | Package_LCC:PLCC-68_THT-Socket
89 | 1 | U21 | 7416 | 74xx_IEEE:7416 | Package_DIP:DIP-14_W7.62mm_LongPads
90 | 1 | U22 | 74LS04 | 74xx:74LS04 | Package_DIP:DIP-14_W7.62mm_LongPads | http://www.ti.com/lit/gpn/sn74LS04
91 | 1 | U23 | UM61512A | cbm-steve:UM61512A | Package_DIP:DIP-32_W7.62mm
92 | 2 | U24, U25 | 74LS641 | 74xx_IEEE:74LS641 | Package_DIP:DIP-20_W7.62mm_LongPads
93 | 1 | U26 | LM7809_TO220 | Regulator_Linear:LM7809_TO220 | Package_TO_SOT_THT:TO-220-3_Vertical | https://www.onsemi.cn/PowerSolutions/document/MC7800-D.PDF
94 | 1 | U27 | AD725 | Video:AD725 | Package_SO:SOIC-16W_7.5x10.3mm_P1.27mm | https://www.analog.com/media/en/technical-documentation/data-sheets/AD725.pdf
95 | 1 | U84 | Z80CPU-LCC | Zilog_z80:Z80CPU-LCC | Package_LCC:PLCC-44_THT-Socket | https://www.mouser.co.uk/datasheet/2/450/ps0178-19386.pdf | Zilog | Z84C00
96 | 1 | UD3 | 74LS00 | 74xx:74LS00 | Package_DIP:DIP-14_W7.62mm | http://www.ti.com/lit/gpn/sn74ls00
97 | 1 | UE1 | 74159 | 74xx_IEEE:74159 | Package_DIP:DIP-24_W15.24mm_LongPads
98 | 2 | X1, X10 | CXO_DIP8 | Oscillator:CXO_DIP8 | Oscillator:Oscillator_DIP-8 | http://cdn-reichelt.de/documents/datenblatt/B400/OSZI.pdf
99 | 1 | X3 | 1.8432 MHz, HC49U | Super8296-rescue:Crystal-superpet-rescue | Crystal:Crystal_HC49-U_Vertical

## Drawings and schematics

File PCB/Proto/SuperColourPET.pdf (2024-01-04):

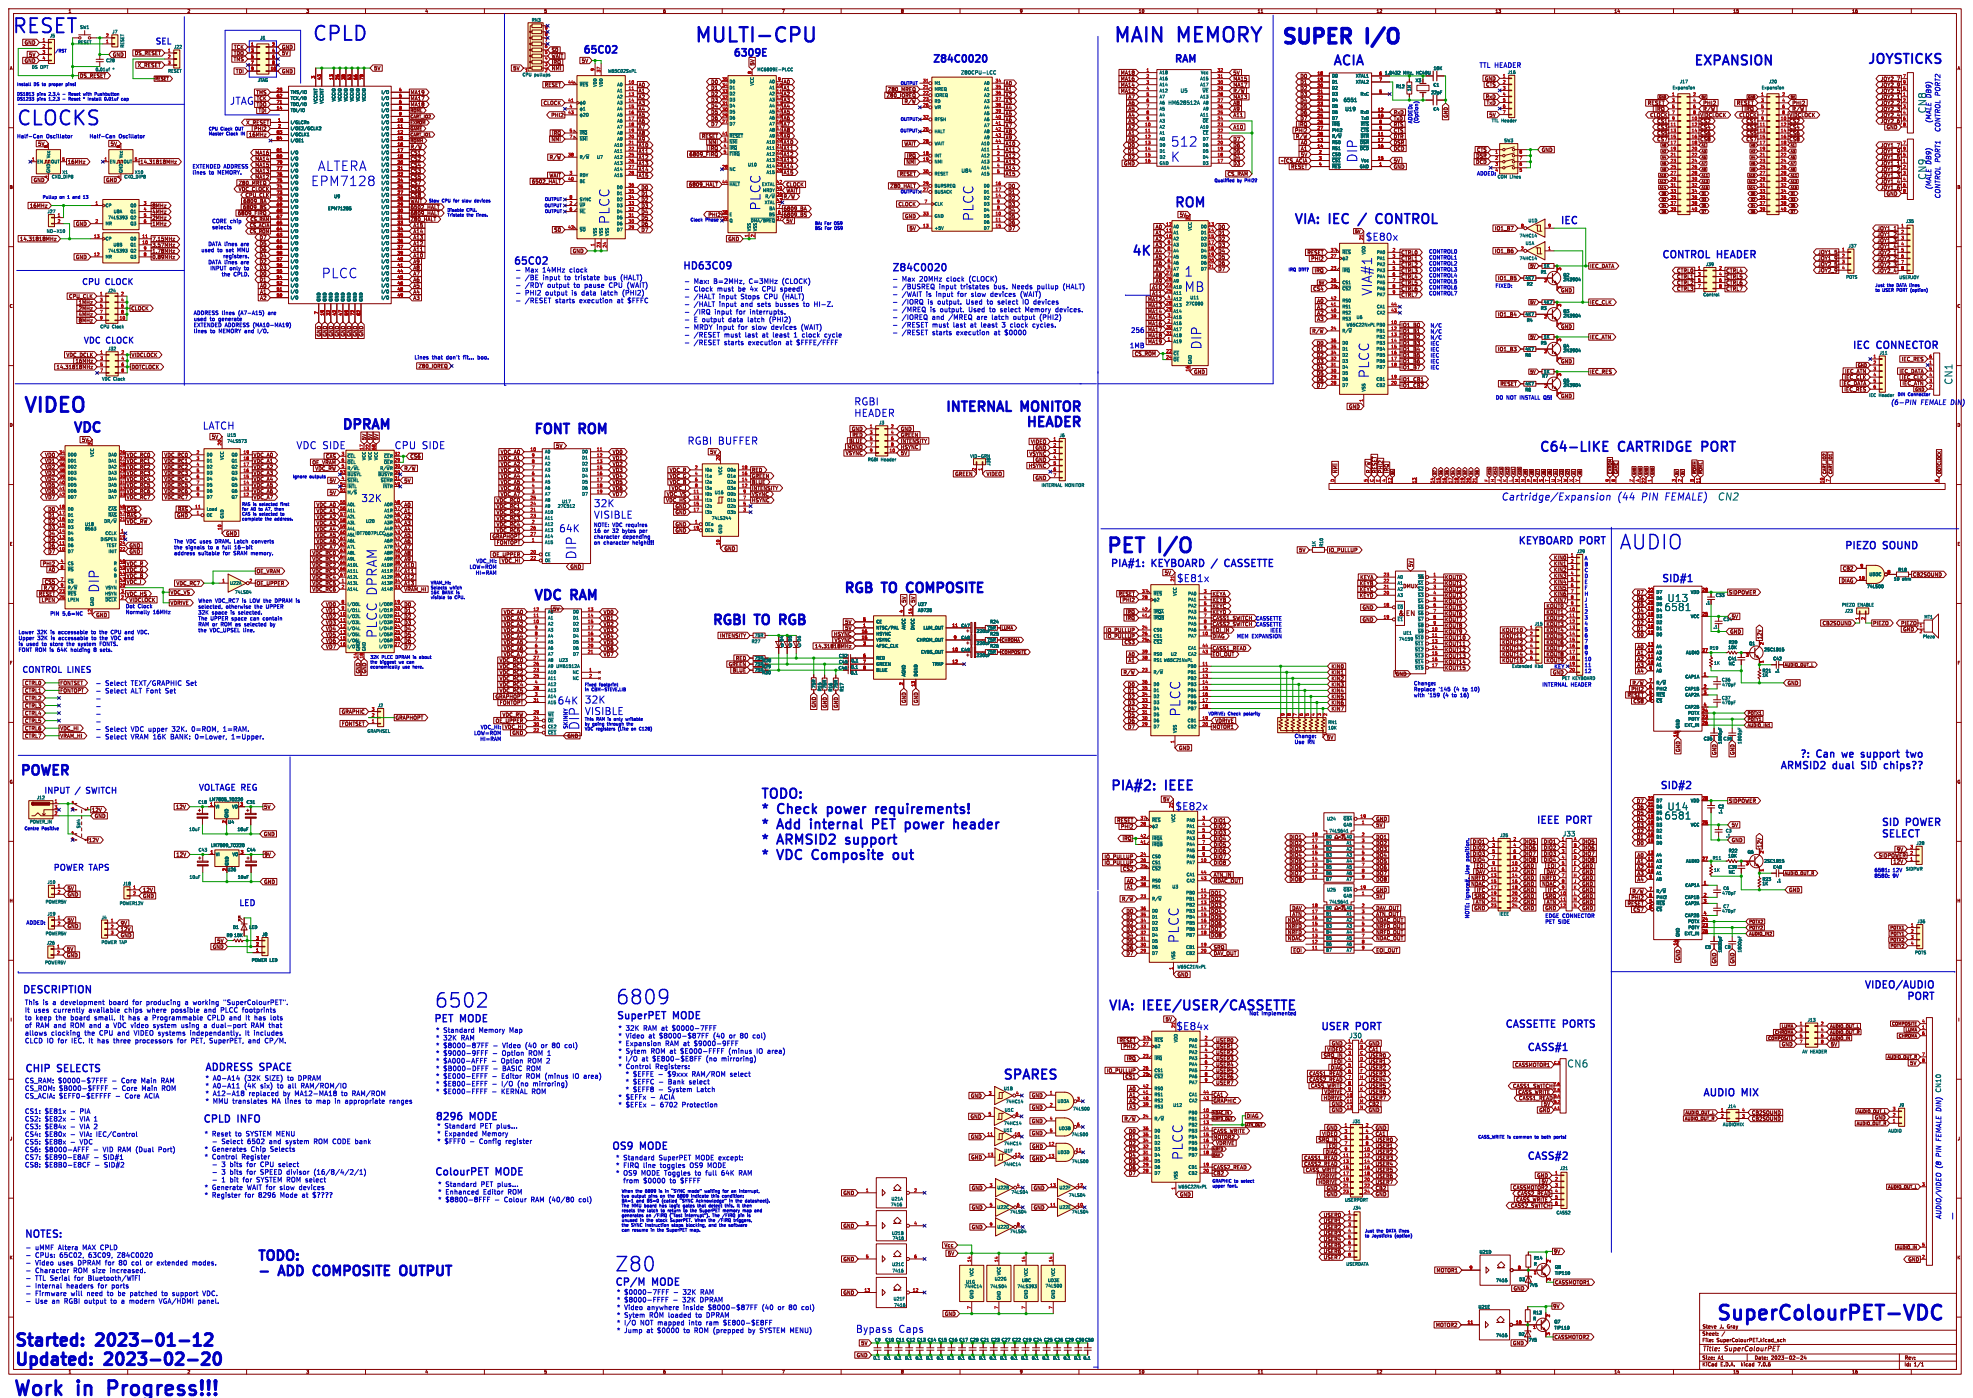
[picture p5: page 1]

1 A0 10 A1 11 A2 13 A3 14 A4 15 A5 16 A6 17 A7 18 A8 19 ~{VP} 2 A9 20 A10 21 A11 22 VSS 23 VSS 24 A12 25 A13 26 A14 27 A15 28 D7 29 RDY 3 D6 30 D5 31 D4 32 D3 33 D2 34 D1 35 D0 36 VDD 37

2 A10 20 A11 21 A12 22 A13 24 A14 25 A15 26 D7 27 NC 28 D6 29 ~{NMI} 3 D5 30 D4 31 D3 32 D2 33 D1 34 D0 35 R/~{W}36 ~{DMA/BREQ}37 E

DO NOT INSTALL Q5! ADDED: (Option)
TxD

Slow CPU for slow devices
~{6809_HALT}

Disable CPU. Tristate the lines.

DATA lines are
used to set MMU
registers. DATA lines are

- Max 14MHz clock
- /RDY output to pause CPU (WAIT)

- Max: B=2MHz, C=3MHz (CLOCK)
- Clock must be 4x CPU speed! - /HALT input Stops CPU (HALT)

- /WAIT is input for slow devices (WAIT)
- /IORQ is output. Used to select IO devices
- /MREQ is output. Used to select Memory devices. - /IOREQ and /MREQ are latch output (PHI2)

Just the DATA lines
to USER PORT (option)

- PHI2 output is data latch (PHI2)

- /HALT input and sets busses to HI-Z. - /IRQ input for interrupts. - E output data latch (PHI2)

used to generate EXTENDED ADDRESS (MA10-MA19)

- MRDY input for slow devices (WAIT)
- /RESET must last at least 1 clock cycle

lines to MEMORY and I/O.

Lines that don't fit... boo.
Z80_IOREQ

The VDC uses DRAM. Latch converts

VDC_HI:
LOW=ROM
HI=RAM
VDC RAM SKINNY DIP

When VDC_RC7 is LOW the DPRAM is
32K space is selected. The UPPER space can contain RAM or ROM as selected by

FONT ROM is 64K holding 8 sets. PIN 5,6=NC

is used to store the system FONTS.

32K PLCC DPRAM is about
the biggest we can
GRAPHOPT GND

- Select TEXT/GRAPHIC Set - Select ALT Font Set -

Change:
Replace '145 (4 to 10) with '159 (4 to 16)

- Select VDC upper 32K. 0=ROM, 1=RAM. - Select VRAM 16K BANK: 0=Lower, 1=Upper.

This RAM is only writable

* Check power requirements!
* Add internal PET power header
* ARMSID2 support

* Reset to SYSTEM MENU
- Select 6502 and system ROM CODE bank
* Generates Chip Selects
* Control Register
- 3 bits for CPU select - 3 bits for SPEED divisor (16/8/4/2/1)

CASS_WRITE is common to both ports!

can resume in the SuperPET map. OS9 MODE
* Standard SuperPET MODE except: * FIRQ line toggles OS9 MODE

* OS9 MODE Toggles to full 64K RAM
from $0000 to $FFFF

- 1 bit for SYSTEM ROM select * Generate WAIT for slow devices

GRAPHIC to select upper font.

* Standard PET plus... * Enhanced Editor ROM

When the 6809 is in þÿ SYNCþÿmode  waiting for an interrupt,

* Register for 8296 Mode at $????

resets the latch to return to the SuperPET memory map and

- uMMF Altera MAX CPLD
- CPUs: 65C02, 63C09, Z84C0020
- Video uses DPRAM for 80 col or extended modes. - Character ROM size increased. - TTL Serial for Bluetooth/WiFi - Internal headers for ports

- Firmware will need to be patched to support VDC. - Use an RGBI output to a modern VGA/HDMI panel.

* I/O NOT mapped into ram $E800-$E8FF
* Jump at $0000 to ROM (prepped by SYSTEM MENU)

File: SuperColourPET.kicad_sch Sheet: / Steve J. Gray

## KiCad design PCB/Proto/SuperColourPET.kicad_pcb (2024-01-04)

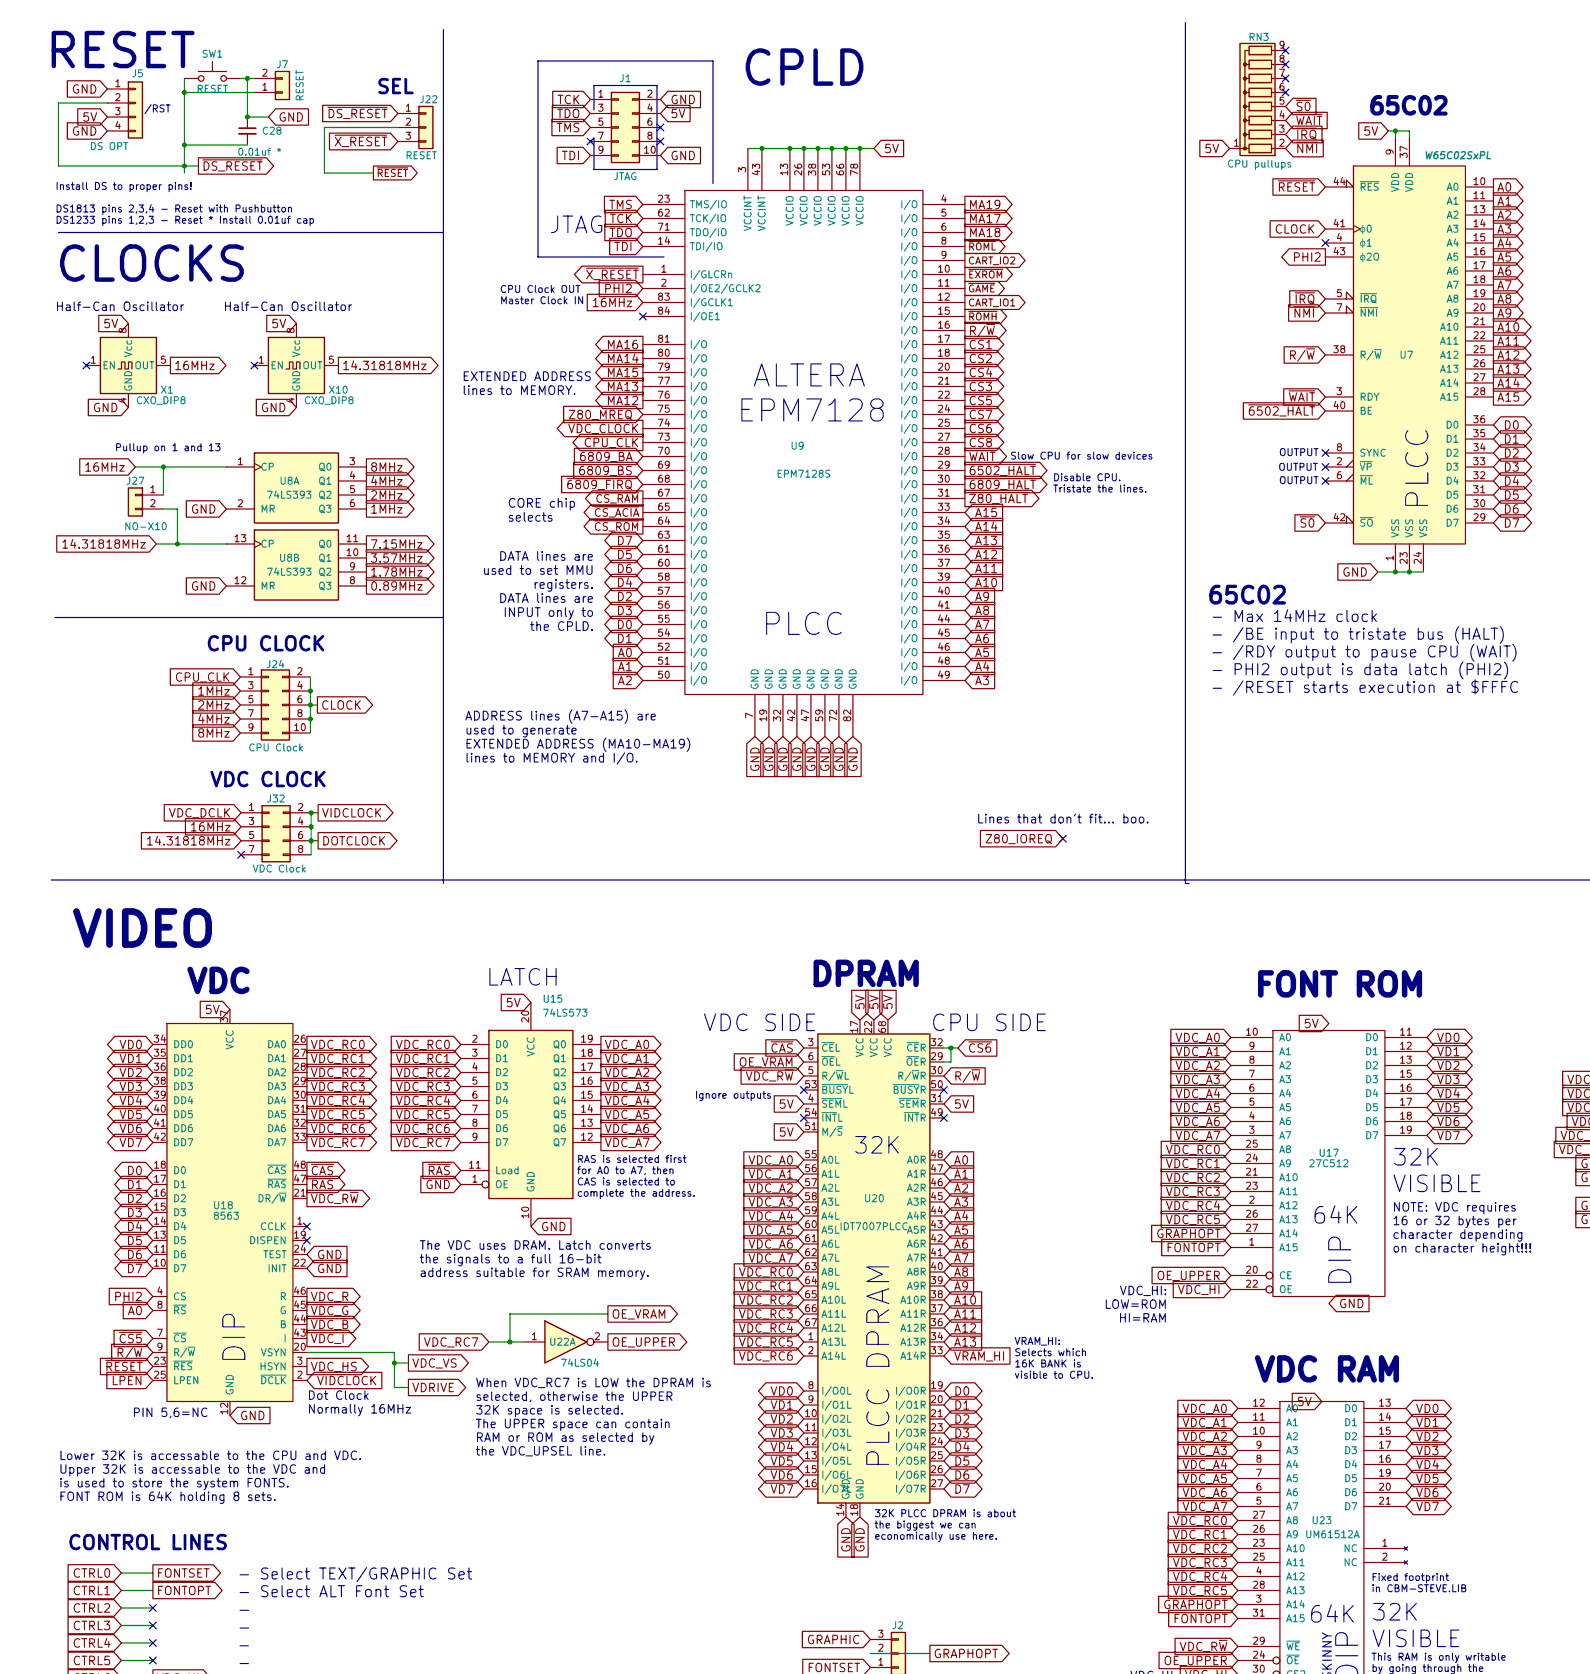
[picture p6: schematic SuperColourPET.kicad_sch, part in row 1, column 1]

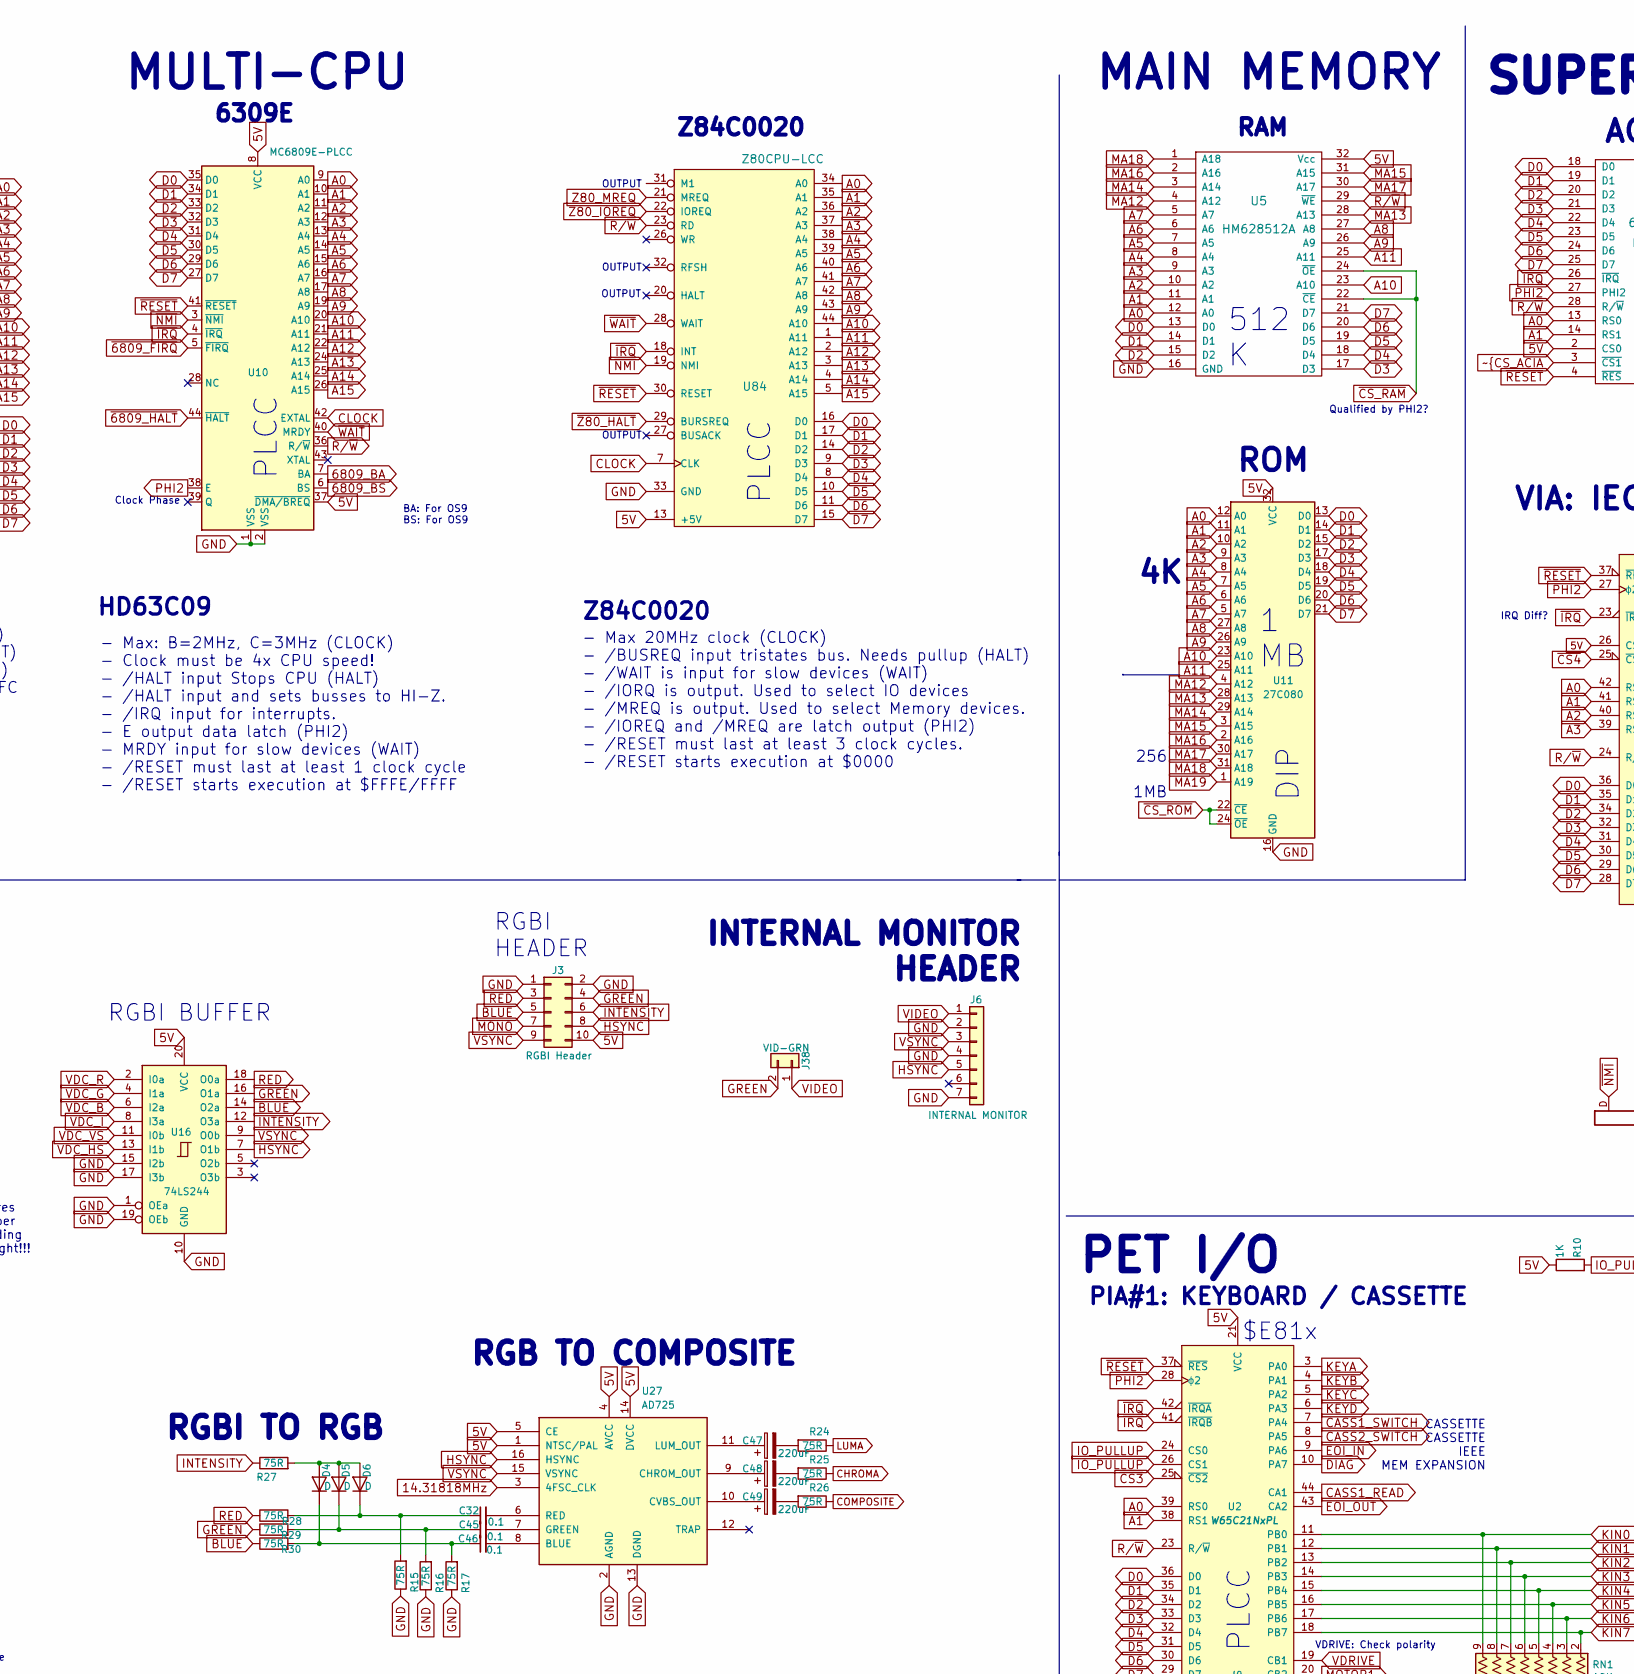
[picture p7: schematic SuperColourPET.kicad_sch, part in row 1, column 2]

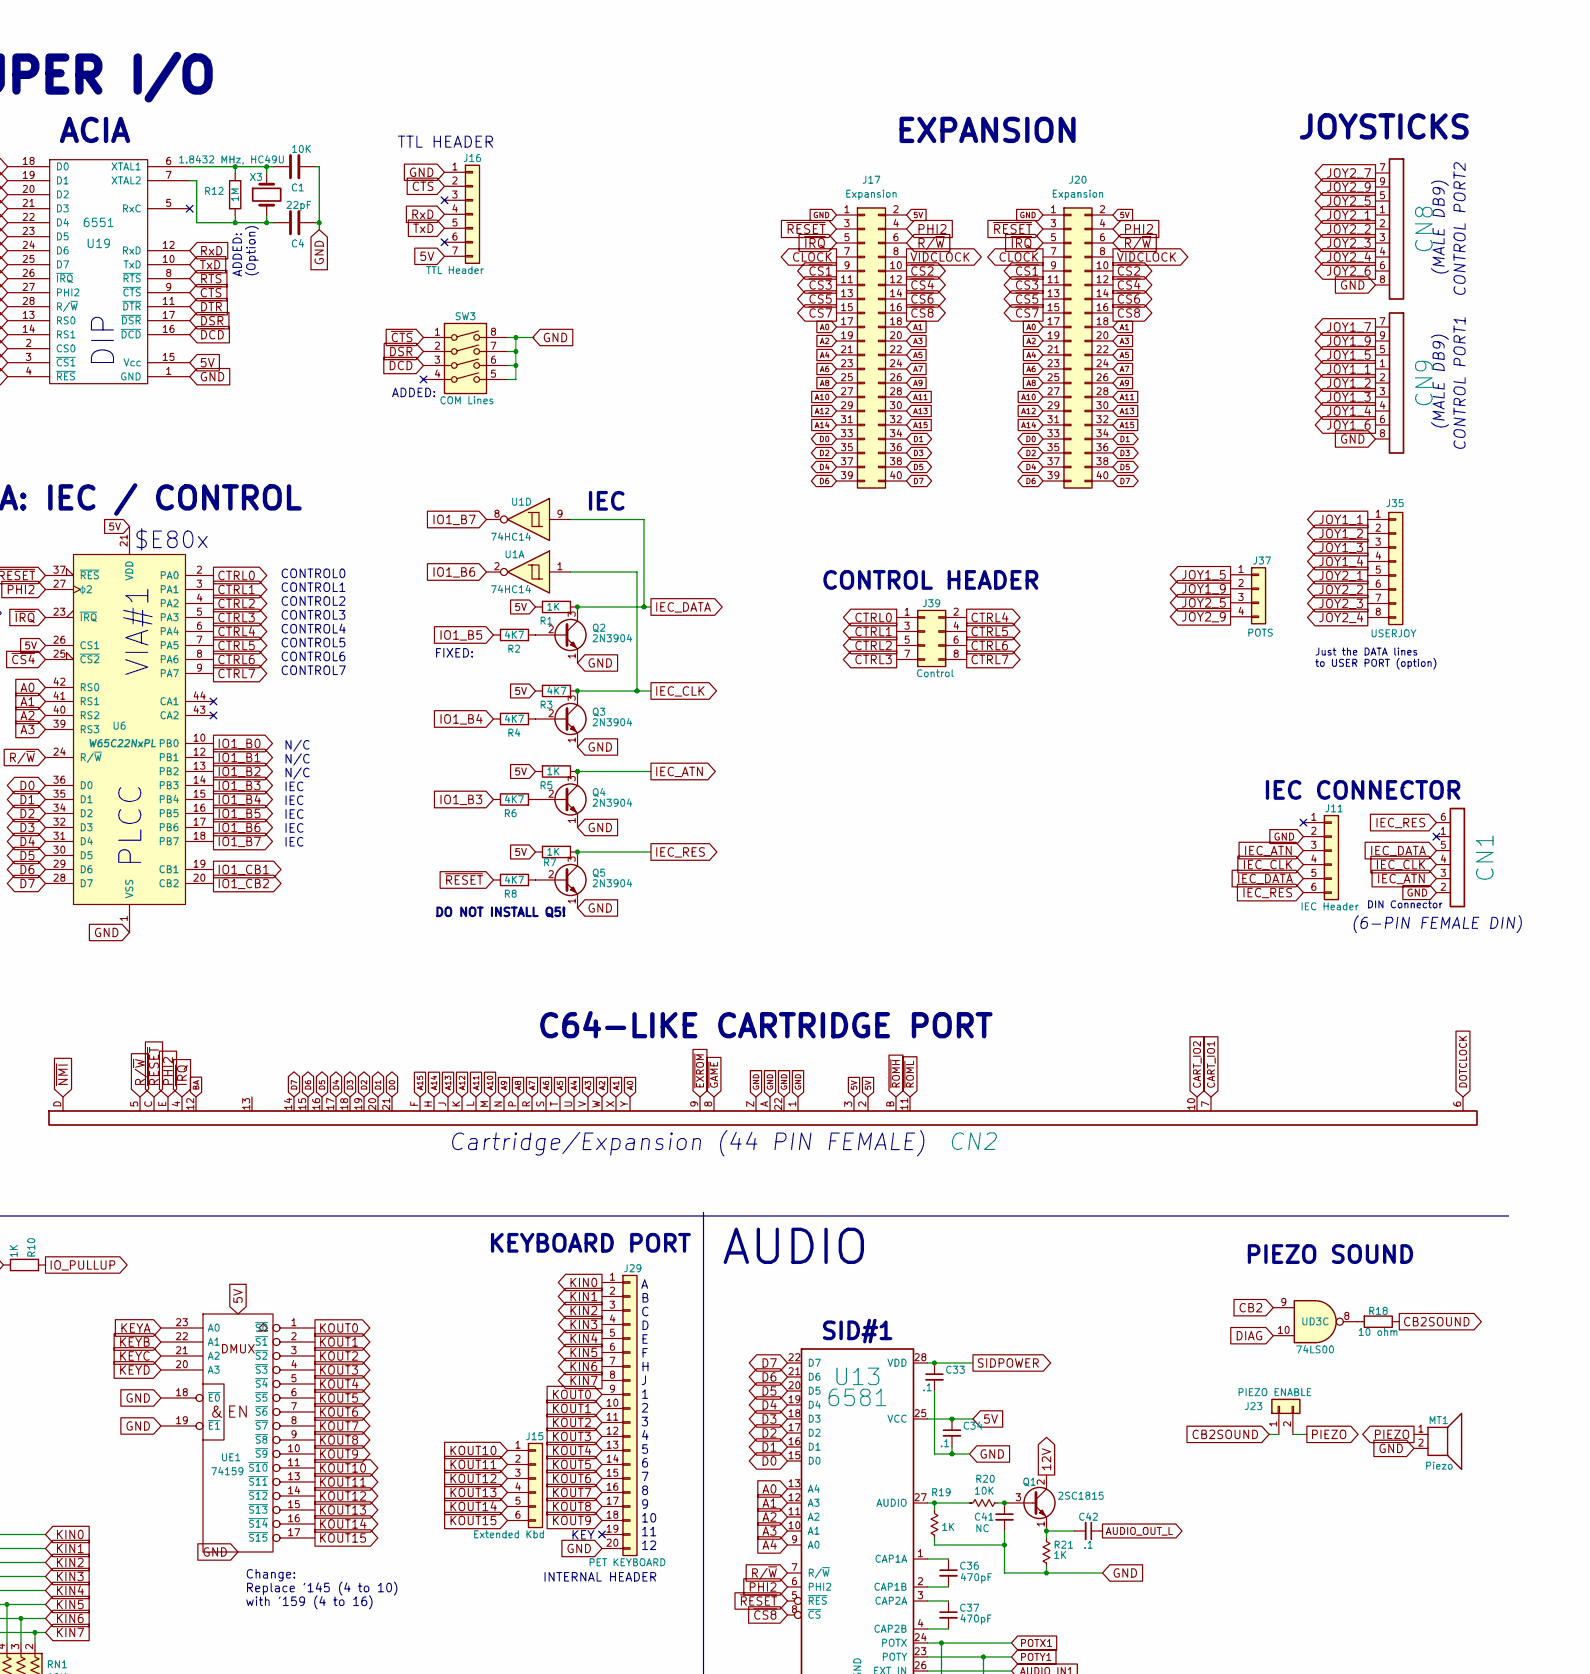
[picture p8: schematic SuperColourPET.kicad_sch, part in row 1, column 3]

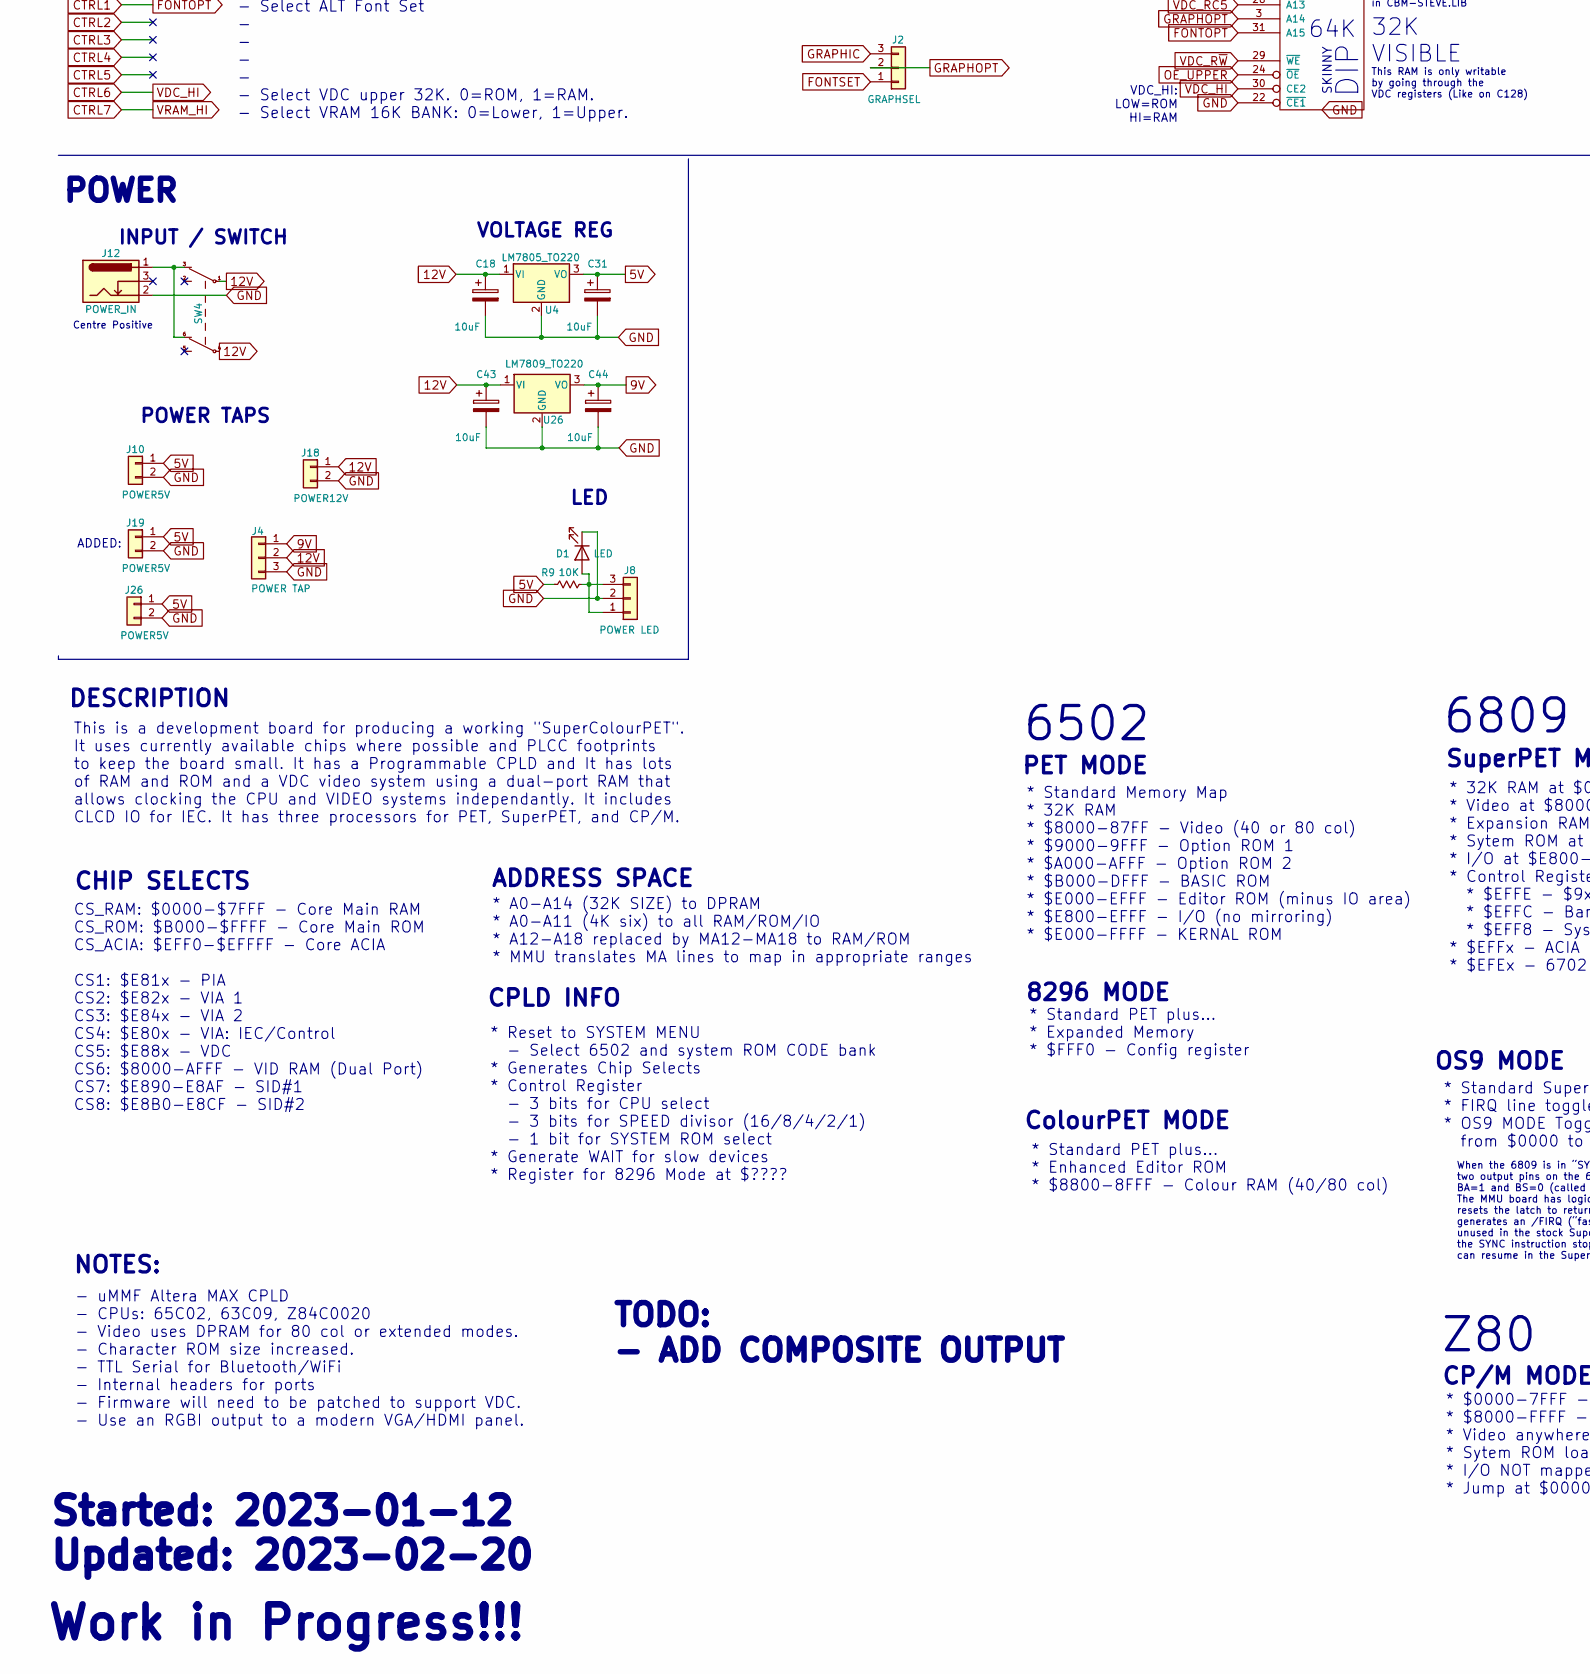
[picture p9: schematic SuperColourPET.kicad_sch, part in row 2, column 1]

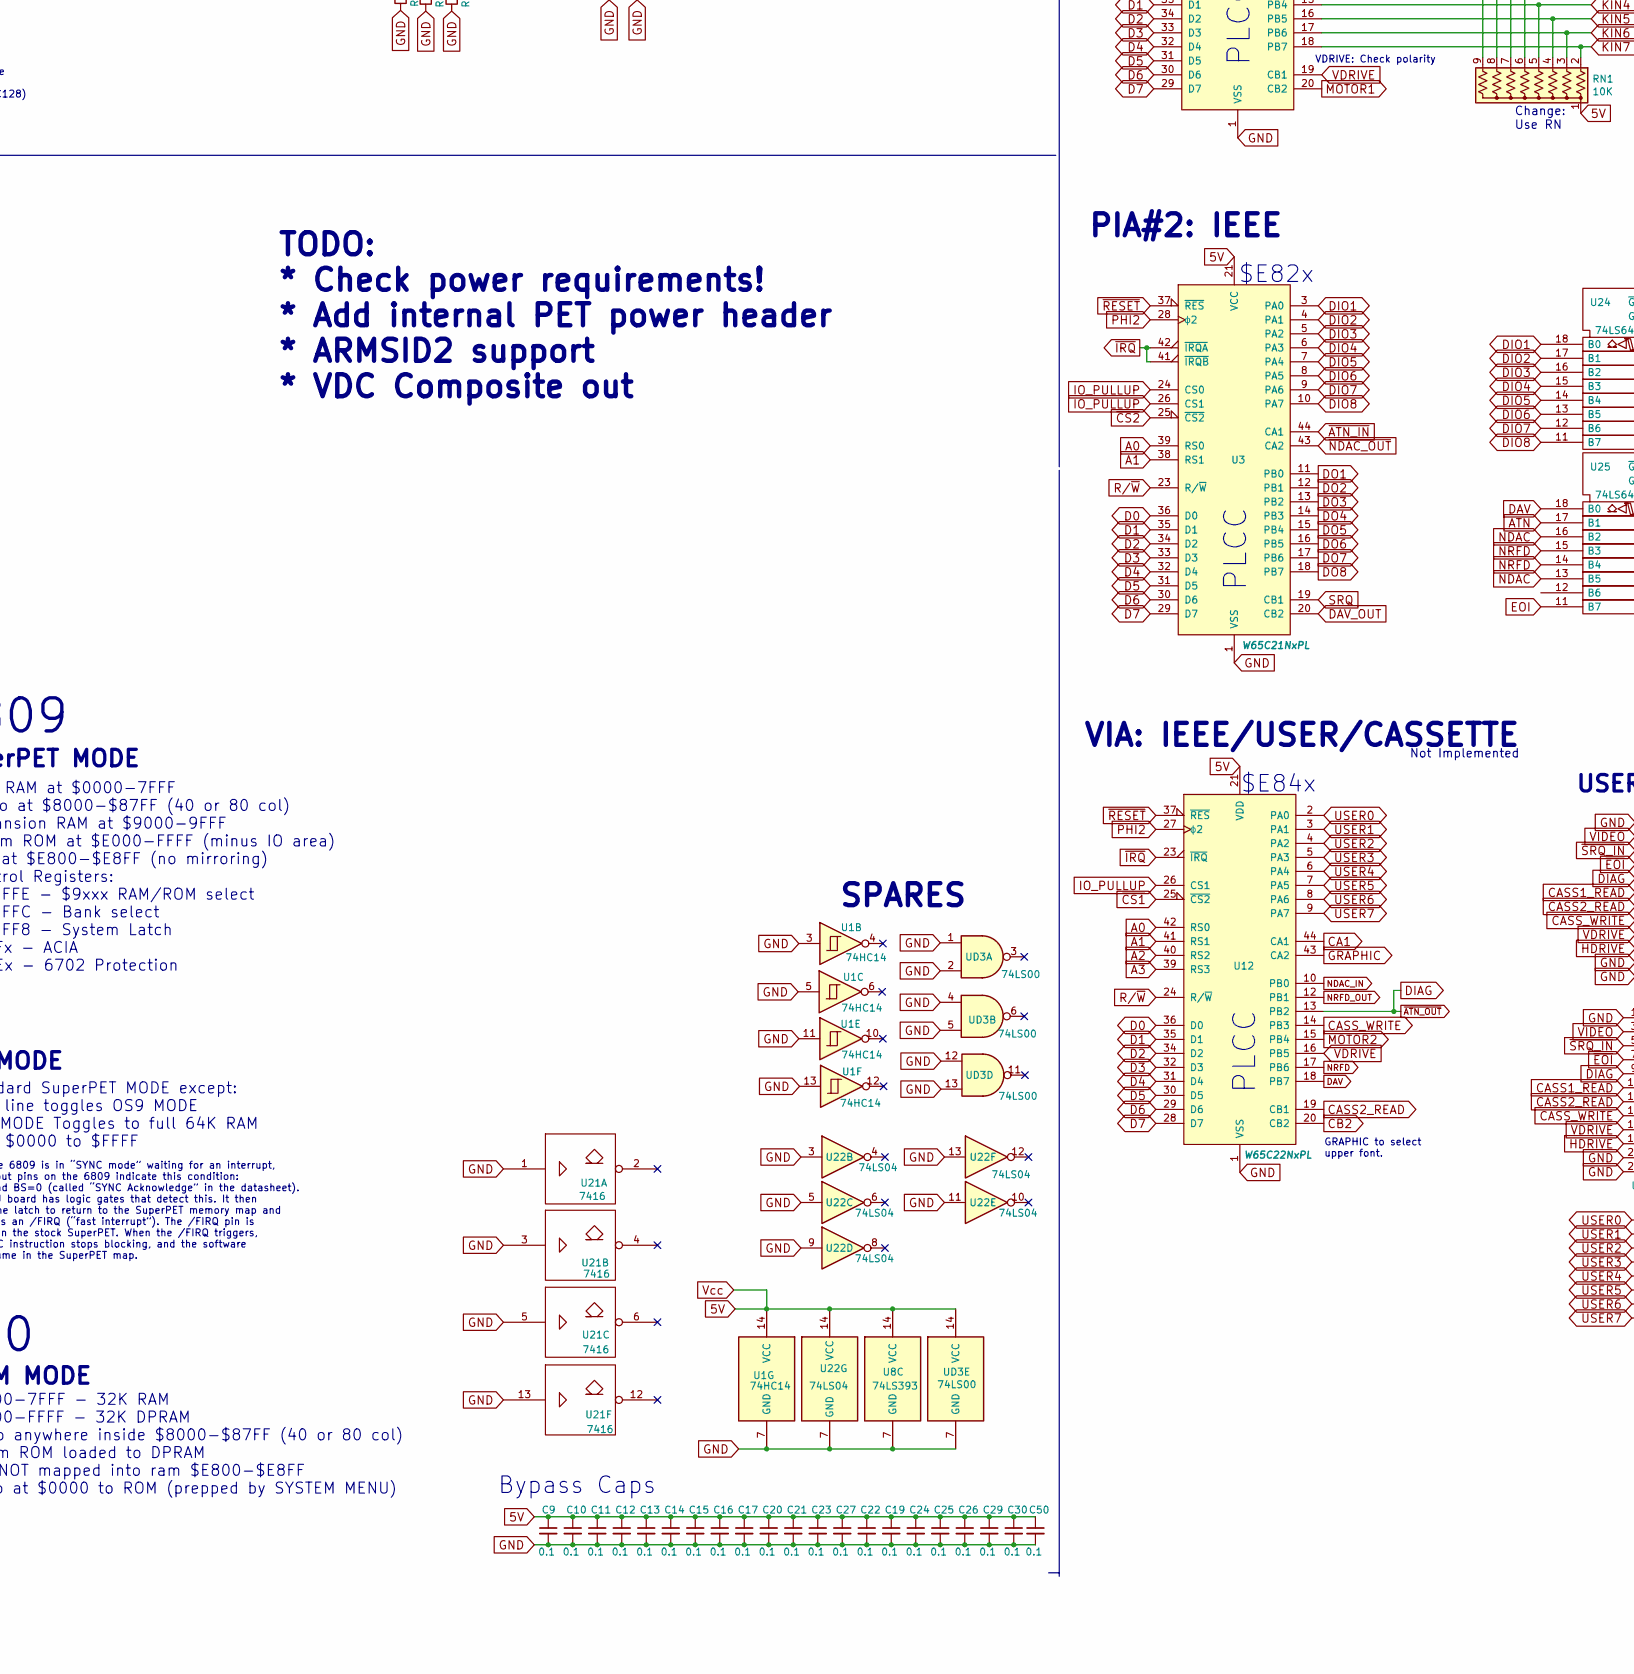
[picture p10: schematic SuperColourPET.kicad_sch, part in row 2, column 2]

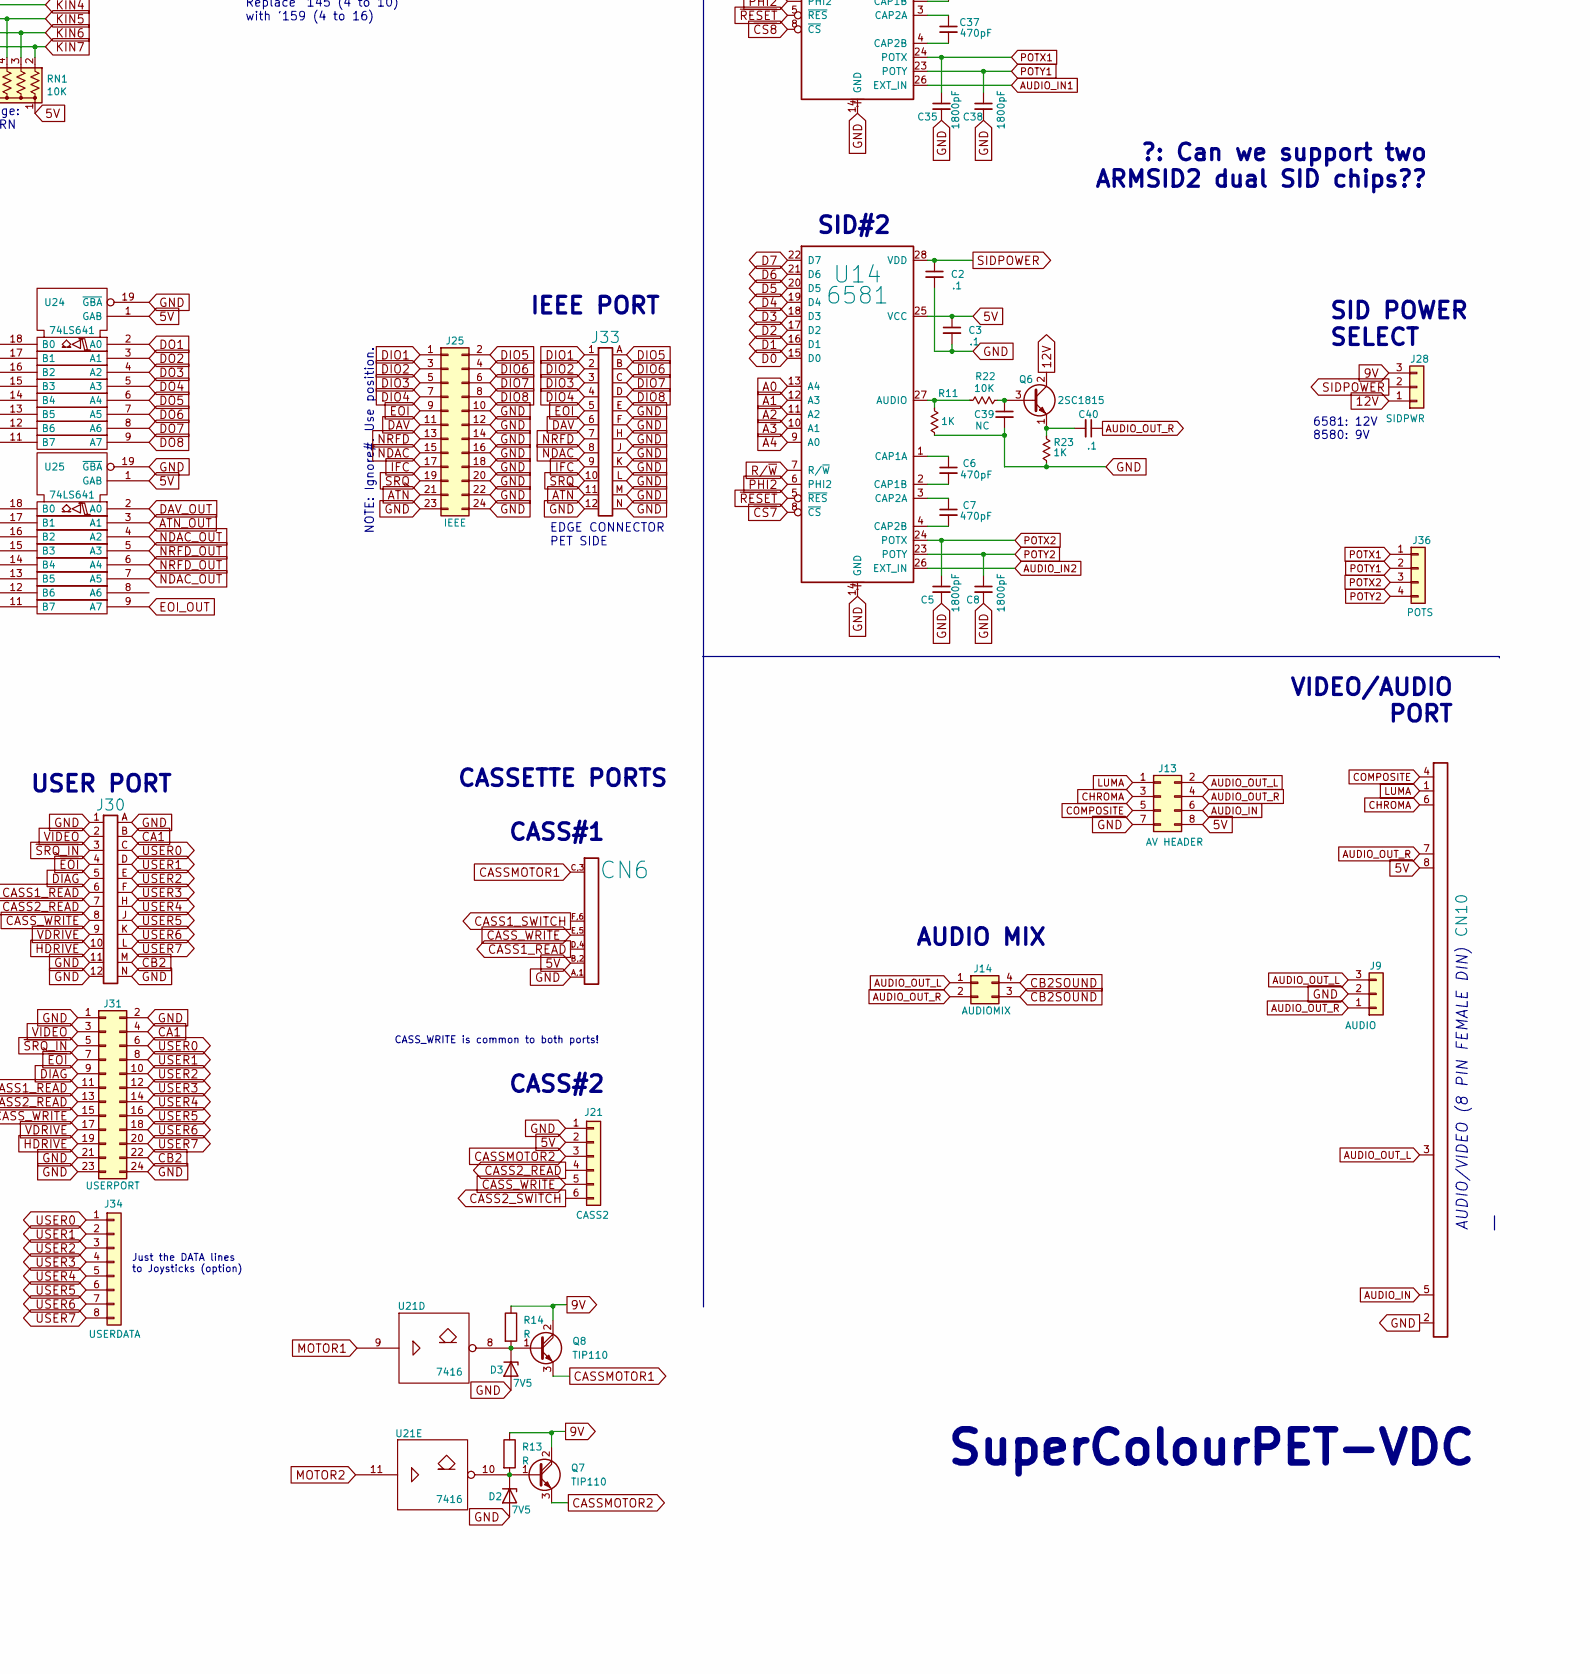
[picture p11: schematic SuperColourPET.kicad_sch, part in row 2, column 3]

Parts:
C1: 10K; C_Disc_D4.7mm_W2.5mm_P5.00mm
C2, C3, C33, C34, C40, C42: .1; C_Disc_D4.7mm_W2.5mm_P5.00mm
C4: 22pF; C_Disc_D4.7mm_W2.5mm_P5.00mm
C5, C8, C35, C38: 1800pF; C_Disc_D4.7mm_W2.5mm_P5.00mm
C6, C7, C36, C37: 470pF; C_Disc_D4.7mm_W2.5mm_P5.00mm
C9, C10, C11, C12, C13, C14, C15, C16, C17, C19, C20, C21, C22, C23, C24, C25, C26, C27, C29, C30, C32, C45, C46, C50: 0.1; C_Disc_D4.7mm_W2.5mm_P5.00mm
C18, C31, C43, C44: 10uF; CP_Radial_D7.5mm_P2.50mm
C28: 0.01uf *; C_Disc_D4.7mm_W2.5mm_P5.00mm
C39, C41: NC; C_Disc_D4.7mm_W2.5mm_P5.00mm
C47, C48, C49: 220uF; CP_Radial_D4.0mm_P1.50mm
CN1: SERIAL_BUS_CON; SERIAL_CON_DIN6
CN2: EXPANSION_PORT
CN6: CASS1; EDGE_CON_12P_TAPE
CN8, CN9: CONTROL_PORT; JOYPORT_DB9
CN10: AV_CONN; AV_CON_DIN8
D1: LED; LED_D3.0mm
D2, D3: 7V5; D_A-405_P10.16mm_Horizontal
D4, D5, D6: D; D_A-405_P2.54mm_Vertical_AnodeUp
J1: JTAG; PinHeader_2x05_P2.54mm_Vertical
J2: GRAPHSEL; PinHeader_1x03_P2.54mm_Vertical
J3: RGBI Header; PinHeader_2x05_P2.54mm_Vertical
J4: POWER TAP; PinHeader_1x03_P2.54mm_Vertical
J5: DS OPT; PinHeader_1x04_P2.54mm_Vertical
J6: INTERNAL MONITOR; PinHeader_1x07_P2.54mm_Vertical
J7: RESET; PinHeader_1x02_P2.54mm_Vertical
J8: POWER LED; PinHeader_1x03_P2.54mm_Vertical
J9: AUDIO; PinHeader_1x03_P2.54mm_Vertical
J10, J19, J26: POWER5V; PinHeader_1x02_P2.54mm_Vertical
J11: IEC Header; PinHeader_1x06_P2.54mm_Vertical
J12: POWER_IN; BarrelJack_Horizontal
J13: AV HEADER; PinHeader_2x04_P2.54mm_Vertical
J14: AUDIOMIX; PinHeader_2x02_P2.54mm_Vertical
J15: Extended Kbd; PinHeader_1x06_P2.54mm_Vertical
J16: TTL Header; PinHeader_1x07_P2.54mm_Vertical
J17, J20: Expansion; PinHeader_2x20_P2.54mm_Vertical
J18: POWER12V; PinHeader_1x02_P2.54mm_Vertical
J21: CASS2; PinHeader_1x06_P2.54mm_Vertical
J22: RESET; PinHeader_1x03_P2.54mm_Vertical
J23: PIEZO ENABLE; PinHeader_1x02_P2.54mm_Vertical
J24: CPU Clock; PinHeader_2x05_P2.54mm_Vertical
J25: IEEE; PinHeader_2x12_P2.54mm_Vertical
J27: NO-X10; PinHeader_1x02_P2.54mm_Vertical
J28: SIDPWR; PinHeader_1x03_P2.54mm_Vertical
J29: PET KEYBOARD; PinHeader_1x20_P2.54mm_Vertical
J30: USERPORT; EDGE_CON_24P
J31: USERPORT; PinHeader_2x12_P2.54mm_Vertical
J32: VDC Clock; PinHeader_2x04_P2.54mm_Vertical
J33: IEEE; EDGE_CON_24P
J34: USERDATA; PinHeader_1x08_P2.54mm_Vertical
J35: USERJOY; PinHeader_1x08_P2.54mm_Vertical
J36, J37: POTS; PinHeader_1x04_P2.54mm_Vertical
J38: VID-GRN; PinHeader_1x02_P2.54mm_Vertical
J39: Control; PinHeader_2x04_P2.54mm_Vertical
MT1: Piezo; TestPoint_2Pads_Pitch2.54mm_Drill0.8mm
Q1, Q6: 2SC1815; TO-92_Inline_Wide
Q2, Q3, Q4, Q5: 2N3904; TO-92_Inline_Wide
Q7, Q8: TIP110; TO-220-3_Vertical
R1, R5, R7: 1K; R_Axial_DIN0207_L6.3mm_D2.5mm_P2.54mm_Vertical
R2, R3, R4, R6, R8: 4K7; R_Axial_DIN0207_L6.3mm_D2.5mm_P2.54mm_Vertical
R9, R20, R22: 10K; R_Axial_DIN0204_L3.6mm_D1.6mm_P7.62mm_Horizontal
R10, R11, R19, R21, R23: 1K; R_Axial_DIN0204_L3.6mm_D1.6mm_P7.62mm_Horizontal
R12: 1M; R_Axial_DIN0204_L3.6mm_D1.6mm_P7.62mm_Horizontal
R13, R14: R; R_Axial_DIN0204_L3.6mm_D1.6mm_P7.62mm_Horizontal
R15, R16, R17, R24, R25, R26, R27, R28, R29, R30: 75R; R_Axial_DIN0207_L6.3mm_D2.5mm_P2.54mm_Vertical
R18: 10 ohm; R_Axial_DIN0204_L3.6mm_D1.6mm_P7.62mm_Horizontal
RN1: 10K; R_Array_SIP9
RN3: CPU pullups; R_Array_SIP9
SW1: RESET; SW_Tactile_SPST_Angled_PTS645Vx58-2LFS
SW3: COM Lines; SW_DIP_SPSTx04_Slide_9.78x12.34mm_W7.62mm_P2.54mm
SW4: POWER_SWITCH
U1: 74HC14
U2, U3: W65C21NxPL; PLCC-44_THT-Socket
U4: LM7805_TO220; TO-220-3_Vertical
U5: HM628512A; DIP-32_W15.24mm_LongPads
U6, U12: W65C22NxPL; PLCC-44_THT-Socket
U7: W65C02SxPL; PLCC-44_THT-Socket
U8: 74LS393; DIP-14_W7.62mm_LongPads
U9: EPM7128S; PLCC-84_THT-Socket
U10: MC6809E-PLCC; PLCC-44_THT-Socket
U11: 27C080; DIP-32_W15.24mm_LongPads
U13, U14: 6581; DIP-28_W15.24mm_LongPads
U15: 74LS573; DIP-20_W7.62mm_LongPads
U16: 74LS244; DIP-20_W7.62mm_LongPads
U17: 27C512; DIP-28_W15.24mm_LongPads
U18: 8563; DIP-48_W15.24mm_LongPads
U19: 6551; DIP-28_W15.24mm_LongPads
U20: IDT7007PLCC; PLCC-68_THT-Socket
U21: 7416; DIP-14_W7.62mm_LongPads
U22: 74LS04; DIP-14_W7.62mm_LongPads
U23: UM61512A; DIP-32_W7.62mm
U24, U25: 74LS641; DIP-20_W7.62mm_LongPads
U26: LM7809_TO220; TO-220-3_Vertical
U27: AD725; SOIC-16W_7.5x10.3mm_P1.27mm
U84: Z80CPU-LCC; PLCC-44_THT-Socket; Manufacturer_Part_Number Z84C00
UD3: 74LS00; DIP-14_W7.62mm
UE1: 74159; DIP-24_W15.24mm_LongPads
X1, X10: CXO_DIP8; Oscillator_DIP-8
X3: 1.8432 MHz, HC49U; Crystal_HC49-U_Vertical

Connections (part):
0.89MHz: U8.8 (Q3)
1.78MHz: U8.9 (Q2)
1MHz: J24.3, U8.6 (Q3)
2MHz: J24.5, U8.5 (Q2)
3.57MHz: U8.10 (Q1)
4MHz: J24.7, U8.4 (Q1)
5V: C3.1, C9.1, C10.1, C11.1, C12.1, C13.1, C14.1, C15.1, C16.1, C17.1, C19.1, C20.1, C21.1, C22.1, C23.1, C24.1, C25.1, C26.1, C27.1, C29.1, C30.1, C31.1, C34.1, C50.1, CN2.2, CN2.3, CN6.B,2, CN10.8, J1.4, J3.10, J5.3, J10.1, J13.8, J16.7, J17.2, J19.1, J20.2, J21.2, J26.1, R1.2, R3.2, R5.2, R7.2, R9.2, R10.1, RN1.1 (common), RN3.1 (common), U1.14 (VCC), U2.21 (VCC), U3.21 (VCC), U4.3 (VO), U5.32 (Vcc), U6.21 (VDD), U6.26 (CS1), U7.9 (VDD), U7.37 (VDD), U8.14 (VCC), U9.3 (VCCINT), U9.13 (VCCIO), U9.26 (VCCIO), U9.38 (VCCIO), U9.43 (VCCINT), U9.53 (VCCIO), U9.66 (VCCIO), U9.78 (VCCIO), U10.8 (VCC), U10.37 (~DMA/BREQ), U11.32 (VCC), U12.21 (VDD), U13.25 (VCC), U14.25 (VCC), U15.20 (VCC), U16.20 (VCC), U17.28 (VCC), U18.37 (VCC), U19.2 (CS0), U19.15 (Vcc), U20.4 (~SEML), U20.17 (VCC), U20.22 (VCC)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
7.15MHz: U8.11 (Q0)
8MHz: J24.9, U8.3 (Q0)
9V: C44.1, J4.1, J28.3, Q7.2 (C), Q8.2 (C), R13.1, R14.1, U26.3 (VO)
12V: C18.1, C43.1, J4.2, J18.1, J28.1, Q1.2 (C), Q6.2 (C), SW4.1, SW4.4, U4.1 (VI), U26.1 (VI)
14.31818MHz: J27.2, J32.5, U8.13 (CP), U27.3 (4FSC_CLK), X10.5 (OUT)
16MHz: J27.1, J32.3, U8.1 (CP), U9.83 (I/GCLK1), X1.5 (OUT)
6809_BA: U9.70 (I/O), U10.7 (BA)
6809_BS: U9.69 (I/O), U10.6 (BS)
A0: CN2.Y, J17.17, J20.17, U2.39 (RS0), U3.39 (RS0), U5.12 (A0), U6.42 (RS0), U7.10 (A0), U9.52 (I/O), U10.9 (A0), U11.12 (A0), U12.42 (RS0), U13.13 (A4), U14.13 (A4), U18.8 (~RS), U19.13 (RS0), U20.48 (A0R), U84.34 (A0)
A1: CN2.X, J17.18, J20.18, U2.38 (RS1), U3.38 (RS1), U5.11 (A1), U6.41 (RS1), U7.11 (A1), U9.51 (I/O), U10.10 (A1), U11.11 (A1), U12.41 (RS1), U13.12 (A3), U14.12 (A3), U19.14 (RS1), U20.47 (A1R), U84.35 (A1)
A2: CN2.W, J17.19, J20.19, U5.10 (A2), U6.40 (RS2), U7.13 (A2), U9.50 (I/O), U10.11 (A2), U11.10 (A2), U12.40 (RS2), U13.11 (A2), U14.11 (A2), U20.46 (A2R), U84.36 (A2)
A3: CN2.V, J17.20, J20.20, U5.9 (A3), U6.39 (RS3), U7.14 (A3), U9.49 (I/O), U10.12 (A3), U11.9 (A3), U12.39 (RS3), U13.10 (A1), U14.10 (A1), U20.45 (A3R), U84.37 (A3)
A4: CN2.U, J17.21, J20.21, U5.8 (A4), U7.15 (A4), U9.48 (I/O), U10.13 (A4), U11.8 (A4), U13.9 (A0), U14.9 (A0), U20.44 (A4R), U84.38 (A4)
A5: CN2.T, J17.22, J20.22, U5.7 (A5), U7.16 (A5), U9.46 (I/O), U10.14 (A5), U11.7 (A5), U20.43 (A5R), U84.39 (A5)
A6: CN2.S, J17.23, J20.23, U5.6 (A6), U7.17 (A6), U9.45 (I/O), U10.15 (A6), U11.6 (A6), U20.42 (A6R), U84.40 (A6)
A7: CN2.R, J17.24, J20.24, U5.5 (A7), U7.18 (A7), U9.44 (I/O), U10.16 (A7), U11.5 (A7), U20.41 (A7R), U84.41 (A7)
A8: CN2.P, J17.25, J20.25, U5.27 (A8), U7.19 (A8), U9.41 (I/O), U10.17 (A8), U11.27 (A8), U20.40 (A8R), U84.42 (A8)
A9: CN2.N, J17.26, J20.26, U5.26 (A9), U7.20 (A9), U9.40 (I/O), U10.19 (A9), U11.26 (A9), U20.39 (A9R), U84.43 (A9)
A10: CN2.M, J17.27, J20.27, U5.23 (A10), U7.21 (A10), U9.39 (I/O), U10.20 (A10), U11.23 (A10), U20.38 (A10R), U84.44 (A10)
A11: CN2.L, J17.28, J20.28, U5.25 (A11), U7.22 (A11), U9.37 (I/O), U10.21 (A11), U11.25 (A11), U20.37 (A11R), U84.1 (A11)
A12: CN2.K, J17.29, J20.29, U7.25 (A12), U9.36 (I/O), U10.22 (A12), U20.36 (A12R), U84.2 (A12)
A13: CN2.J, J17.30, J20.30, U7.26 (A13), U9.35 (I/O), U10.24 (A13), U20.34 (A13R), U84.3 (A13)
A14: CN2.H, J17.31, J20.31, U7.27 (A14), U9.34 (I/O), U10.25 (A14), U84.4 (A14)
A15: CN2.F, J17.32, J20.32, U7.28 (A15), U9.33 (I/O), U10.26 (A15), U84.5 (A15)
ATN: J25.21, J33.11, U25.17 (B1)
ATN_OUT: U25.3 (A1)
AUDIO_IN: CN10.5, J13.6
AUDIO_IN1: U13.26 (EXT_IN)
AUDIO_IN2: U14.26 (EXT_IN)
AUDIO_OUT_L: C42.1, CN10.3, J9.3, J13.2, J14.1
AUDIO_OUT_R: C40.1, CN10.7, J9.1, J13.4, J14.2
BA: CN2.12
BLUE: J3.5, R30.1, U16.14 (O2a)
CA1: J30.B, J31.4, U12.44 (CA1)
CART_IO1: CN2.7, U9.12 (I/O)
CART_IO2: CN2.10, U9.9 (I/O)
CASS1_READ: CN6.D,4, J30.6, J31.11, U2.44 (CA1)
CASS1_SWITCH: CN6.F,6, U2.7 (PA4)
CASS2_READ: J21.4, J30.7, J31.13, U12.19 (CB1)
CASS2_SWITCH: J21.6, U2.8 (PA5)
CASSMOTOR1: CN6.C,3, Q8.3 (E)
CASSMOTOR2: J21.3, Q7.3 (E)
CASS_WRITE: CN6.E,5, J21.5, J30.8, J31.15, U12.14 (PB3)
CB2: J30.M, J31.22, U12.20 (CB2), UD3.9
CB2SOUND: J14.3, J14.4, J23.1, R18.1
CHROMA: CN10.6, J13.3, R25.1
CLOCK: J17.7, J20.7, J24.2, J24.4, J24.6, J24.8, J24.10, U7.41 (ϕ0), U10.42 (EXTAL), U84.7 (CLK)
COMPOSITE: CN10.4, J13.5, R26.1
CPU_CLK: J24.1, U9.73 (I/O)
CTRL0: J2.1, J39.1, U6.2 (PA0)
CTRL1: J39.3, U6.3 (PA1), U17.1 (A15), U23.31 (A15)
CTRL2: J39.5, U6.4 (PA2)
CTRL3: J39.7, U6.5 (PA3)
CTRL4: J39.2, U6.6 (PA4)
CTRL5: J39.4, U6.7 (PA5)
CTRL6: J39.6, U6.8 (PA6), U17.22 (OE), U23.30 (CE2)
CTRL7: J39.8, U6.9 (PA7), U20.33 (A14R)
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

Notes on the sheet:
GRAPHIC to select upper font.
VDC_HI: LOW=ROM HI=RAM
SEL
* Standard SuperPET MODE except: * FIRQ line toggles OS9 MODE * OS9 MODE Toggles to full 64K RAM from $0000 to $FFFF
6502
6581: 12V 8580: 9V
This is a development board for producing a working "SuperColourPET". It uses currently available chips where possible and PLCC footprints to keep the board small. It has a Programmable CPLD and It has lots of RAM and ROM and a VDC video system using a dual-port RAM that allows clocking the CPU and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
CHIP SELECTS
SUPER I/O
* Standard Memory Map * 32K RAM * $8000-87FF - Video (40 or 80 col) * $9000-9FFF - Option ROM 1 * $A000-AFFF - Option ROM 2 * $B000-DFFF - BASIC ROM * $E000-EFFF - Editor ROM (minus IO area) * $E800-EFFF - I/O (no mirroring) * $E000-FFFF - KERNAL ROM
CONTROL0 CONTROL1 CONTROL2 CONTROL3 CONTROL4 CONTROL5 CONTROL6 CONTROL7
- Max 14MHz clock - /BE input to tristate bus (HALT) - /RDY output to pause CPU (WAIT) - PHI2 output is data latch (PHI2) - /RESET starts execution at $FFFC
IEC
A B C D E F H J 1 2 3 4 5 6 7 8 9 10 11 12
ROM
8296 MODE
TTL HEADER
PLCC
MAIN MEMORY
$E82x
VOLTAGE REG
CASS_WRITE is common to both ports!
?: Can we support two ARMSID2 dual SID chips??
RGBI BUFFER
AUDIO
JTAG
/RST
CPLD
6809
FIXED:
ADDED:
VIA#1
CP/M MODE
NOTE: VDC requires 16 or 32 bytes per character depending on character height!!!
TODO: * Check power requirements! * Add internal PET power header * ARMSID2 support * VDC Composite out
VDC RAM
AUDIO MIX
ColourPET MODE
PIA#2: IEEE
TODO: - ADD COMPOSITE OUTPUT

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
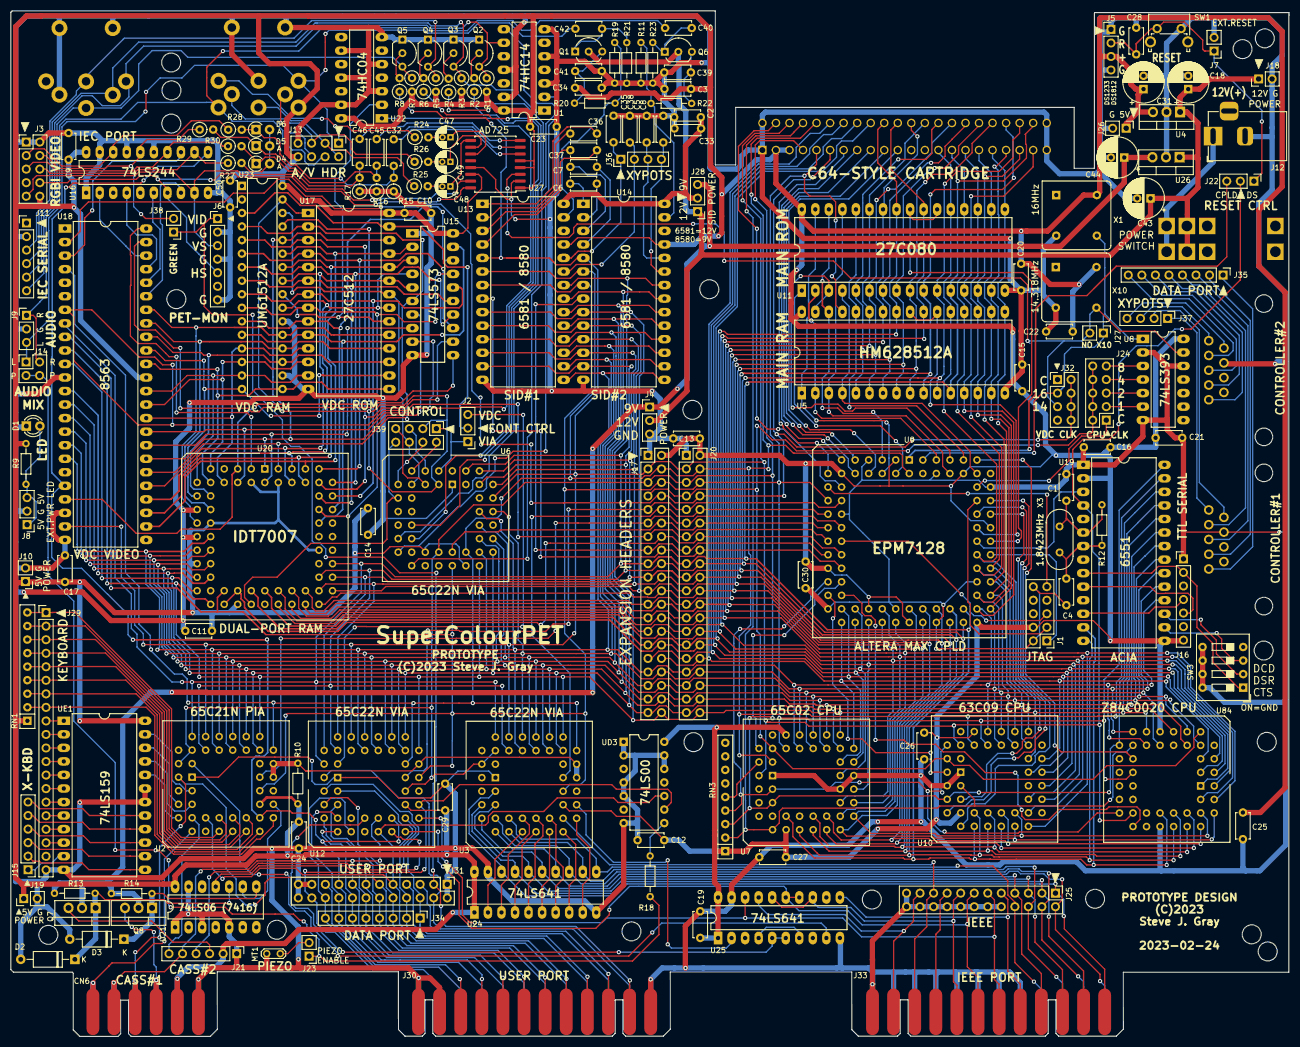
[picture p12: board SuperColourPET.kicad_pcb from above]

Board: 2 copper layers, 239.8 x 192.4 mm, 178 parts (0 on the bottom side), 289 nets.

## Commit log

2024-01-04 PROTO Initial design
    Proto (2023-01-24) PCB designed in Kicad. Untested!!!!!!! Very early design, subject to change!!!!
    [KU-14194HB-REV-B-KiCad.kicad_pcb, KU-14194HB-REV-B-KiCad.kicad_sch, KU-14194HB-REV-B-KiCad.sch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]
2024-02-09 Cleanup unused files
    Cleanup
    [KU-14194HB-REV-B-KiCad.kicad_pcb, KU-14194HB-REV-B-KiCad.kicad_sch, KU-14194HB-REV-B-KiCad.sch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]

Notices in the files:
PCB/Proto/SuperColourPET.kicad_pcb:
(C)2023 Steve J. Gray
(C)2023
